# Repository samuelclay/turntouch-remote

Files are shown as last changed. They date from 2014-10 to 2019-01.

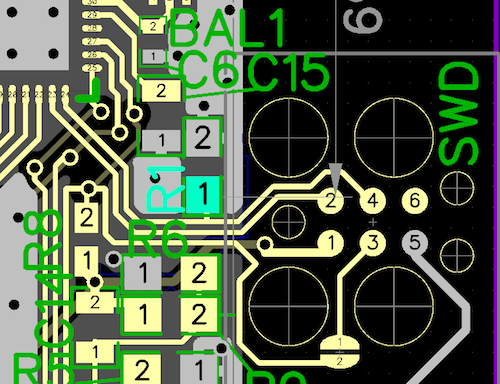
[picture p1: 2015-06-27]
doc/Screen Shot 2013-09-09 at 9.54.04 PM.png

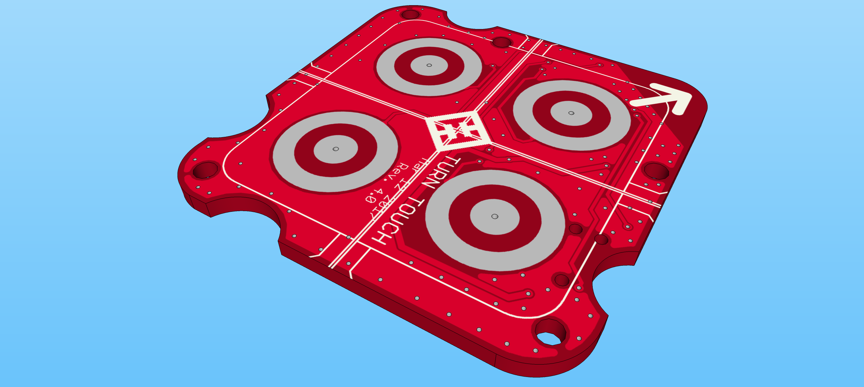
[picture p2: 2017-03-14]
remote eagle/turntuch-bottom-layer.png

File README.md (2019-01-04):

# Turn Touch remote firmware, schematic, and board layout
> The design files used for the nrf51-based Turn Touch remote.

<a href="https://turntouch.com"><br />Available at turntouch.com</a>

[][license-url]



## Screenshots of the board design files

| PCB | EAGLE |
|:---:|:---:|
|  |  |

| Top | Bottom |
|:---:|:---:|
|  |  |

## Background

You can read the complete documentation and background on the [Turn Touch blog series](http://ofbrooklyn.com/2019/01/3/building-turntouch/#firmware).

## Features of the remote

[Turn Touch](https://turntouch.com) is a smart home remote control carved out of beautiful mahogany wood. This is a remote control for Hue lights, Sonos speakers, and all the other connected devices in your home. Turn Touch works on iOS and macOS, giving you control of your music, videos, presentations, and more. 

- [x] **Extraordinary design**: This isn't yet another plastic remote. Turn Touch is carved from solid wood and worked to a show-stopping, textured finish. 
- [x] **Well connected**: Turn Touch connects to most smart devices in your home that speak WiFi. And this is just the first version. Over time, there's no telling what you'll be able to control.
- [x] **Always ready**: Turn Touch is always on, always connected, and always ready to take your breath away. Once you connect your Turn Touch via Bluetooth it stays connected and always available, even without the Turn Touch app actively running. And there's no delay, when you press a button the result is instant.
- [x] **Built to last**: Not only will your Turn Touch stand up to drops and shock — its entire circuit board can be inexpensively replaced with newer, future wireless tech. You won't have to buy a new remote every time Apple comes out with a new phone. And instead of flimsy plastic clasps, a set of 8 strong magnets invisibly hold the remote together. 

## Requirements

- macOS or Windows
- nrf51 Development Kit ([$39 on Digikey](https://www.digikey.com/product-detail/en/nordic-semiconductor-asa/NRF51-DK/1490-1038-ND/5022449))
- EAGLE for schematic and board layout
- ARM toolchain for firmware

## Installation

To install dependencies, start here:

    https://devzone.nordicsemi.com/blogs/22/getting-started-with-nrf51-development-on-mac-os-x/

To use gcc, you will need to download:

 * nRF51 SDK
 * S110 SoftDevice
 * J-Link by Segger
 * srec_cat

    ```$ brew install srecord```

 * GCC ARM Embedded

    When installing GCC tools, do not use "The Unarchiver". It messes up the symlinks for
    all of the binaries. Make sure to use "Archive Utility"
    ```
    $ mv -f ~/Downloads/gcc-arm-none-eabi-4_9-2015q2 ~/projects/code/
    $ ln -s ~/projects/code/gcc-arm-none-eabi-4_9-2015q2 /usr/local/gcc-arm-none-eabi-4_9-2015q2
    ```

 * ./bin/nrfjprog.sh into /usr/local/bin/nrfjprog

### Running

    $ make
    $ make bootloader
    $ make flash
    $ ./bin/nrfjprog.sh --rtt

### Build on Windows

#### Build DFU package

    $ C:\Keil_v5\ARM\ARMCC\bin\fromelf.exe --bin --output Z:\remote\ble_peripheral\ble_app_template\pca10028\s110\arm5\_build\nrf51422_xxac_s110.bin Z:\remote\ble_peripheral\ble_app_template\pca10028\s110\arm5\_build\nrf51422_xxac_s110.axf

    $ & 'C:\Program Files (x86)\Nordic Semiconductor\Master Control Panel\3.10.0.14\nrf\nrfutil.exe' dfu genpkg --sd-req 0xfffe --application Z:\remote\ble_peripheral\ble_app_template\pca10028\s110\arm5\_build\nrf51422_xxac_s110.bin --application-version 0x06 --dev-revision 0x01 Z:\remote\ble_peripheral\nrf51_06.zip

##### Back on Mac

    $ cp ../ble_peripheral/nrf51_*.zip ../../app/Turn\ Touch\ Mac/DFU/firmwares/
    $ cp ../ble_peripheral/nrf51_*.zip ../../ios/Turn\ Touch\ iOS/DFU/

##### In Xcode (in both turntouch-mac/turntouch-ios repos)

In Supporting Files/defaults.plist, change `TT:firmware:version`

#### Build flash hex

    $ mergehex -m Z:/remote/firmware/libs/components/softdevice/s110/hex/s110_nrf51_8.0.0_softdevice.hex Z:/remote/ble_peripheral/dfu/bootloader/pca10028/dual_bank_ble_s110/arm5/_build/nrf51422_xxac.hex Z:/remote/ble_peripheral/ble_app_template/pca10028/s110/arm5/_build/nrf51422_xxac_s110.hex -o Z:/remote/ble_peripheral/nrf51_sd_bootloader_app.hex

#### `make flashwin` on Mac in firmware/

### Upgrading to latest nrf51 SDK

 1) Replace app_error.c with RTT logs
 2) Add BSP_BUTTON_ACTION_LONG_PUSH and BSP_BUTTON_ACTION_RELEASE to bsp.c

## Contribute

We would love you for the contribution to the **Turn Touch remote firmware**. Feel free to submit a Pull Request with the improvements or additions you've made.

## Turn Touch open source repositories and documentation

Everything about Turn Touch is open source and well documented. Here are all of Turn Touch's repos:

* [Turn Touch Mac OS app](https://github.com/samuelclay/turntouch-mac/)
* [Turn Touch iOS app](https://github.com/samuelclay/turntouch-ios/)
* [Turn Touch remote firmware and board layout](https://github.com/samuelclay/turntouch-remote/)
* [Turn Touch enclosure, CAD, and CAM](https://github.com/samuelclay/turntouch-enclosure/)

The entire Turn Touch build process is also documented:
* <a href="http://ofbrooklyn.com/2019/01/3/building-turntouch/">Everything you need to build your own Turn Touch smart remote<br /><img src="https://s3.amazonaws.com/static.newsblur.com/turntouch/blog/1*1_w7IlHISYWdQjIGPcxRkQ.jpeg" width="400"></a>
* <a href="http://ofbrooklyn.com/2019/01/3/building-turntouch/#firmware">Step one: Laying out the buttons and writing the firmware <br /><img src="https://s3.amazonaws.com/static.newsblur.com/turntouch/blog/1*K_ERgjIZiFIX5yDOa5JJ7g.png" width="400"></a>
* <a href="http://ofbrooklyn.com/2019/01/3/building-turntouch/#cad">Step two: Designing the remote to have perfect button clicks <br /><img src="https://s3.amazonaws.com/static.newsblur.com/turntouch/blog/1*iXMqpq5IsfudAeT3GZlLFA.png" width="400"></a>
* <a href="http://ofbrooklyn.com/2019/01/3/building-turntouch/#cnc">Step three: CNC machining and fixturing to accurately cut wood <br /><img src="https://s3.amazonaws.com/static.newsblur.com/turntouch/blog/1*SYmywFE5tY3GBO9t9lcTiA.png" width="400"></a>
* <a href="http://ofbrooklyn.com/2019/01/3/building-turntouch/#laser">Step four: Inlaying the mother of pearl <br /><img src="https://s3.amazonaws.com/static.newsblur.com/turntouch/blog/1*kl8WDuTd0RpCkkipLeHx0g.png" width="400"></a>

## Author

Samuel Clay – [@samuelclay](https://twitter.com/samuelclay) – [samuelclay.com](http://samuelclay.com)

Distributed under the MIT license. See ``LICENSE`` for more information.

[https://github.com/samuelclay/turntouch-mac](https://github.com/samuelclay)

[swift-image]:https://img.shields.io/badge/swift-3.0-orange.svg
[swift-url]: https://swift.org/
[license-image]: https://img.shields.io/badge/License-MIT-blue.svg
[license-url]: LICENSE
[travis-image]: https://img.shields.io/travis/dbader/node-datadog-metrics/master.svg?style=flat-square
[travis-url]: https://travis-ci.org/dbader/node-datadog-metrics
[codebeat-image]: https://codebeat.co/badges/c19b47ea-2f9d-45df-8458-b2d952fe9dad
[codebeat-url]: https://codebeat.co/projects/github-com-vsouza-awesomeios-com

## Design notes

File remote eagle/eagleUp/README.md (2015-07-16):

Steps to import Eagle model into Inventor:

1) Run UDP for EagleUp, use 0 mm for height
2) Import into Sketchup using EagleUp plugin
3) In Sketchup, hit ⌘1 to show top view
4) Export as .DXF (autocad drawing) in 2d
5) Import in Inventor as DXF
6) Create a new part file with PCB, extrude sketch to height 0.7mm = 0.028"

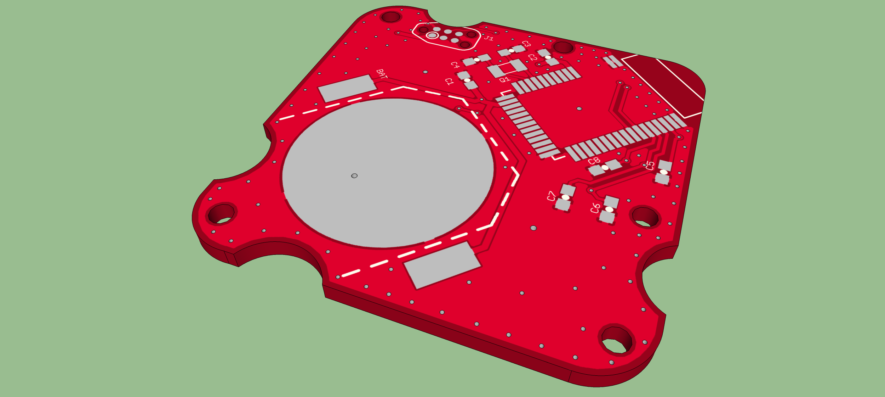
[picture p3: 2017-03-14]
remote eagle/turntuch-top-layer.png

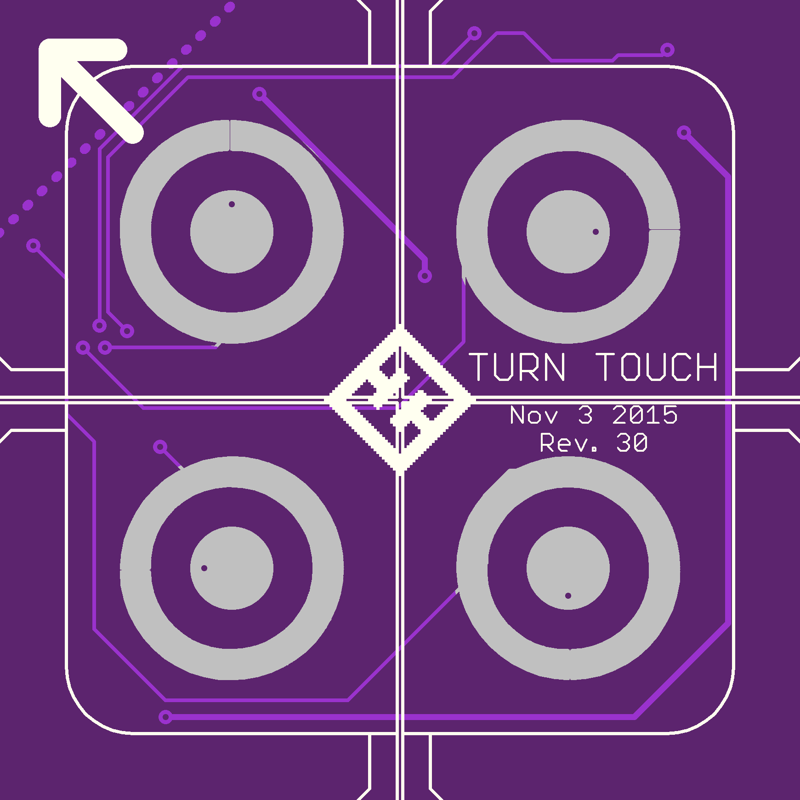
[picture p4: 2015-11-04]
remote eagle/eagleUp/eagleUp_remote_board_bottom.png

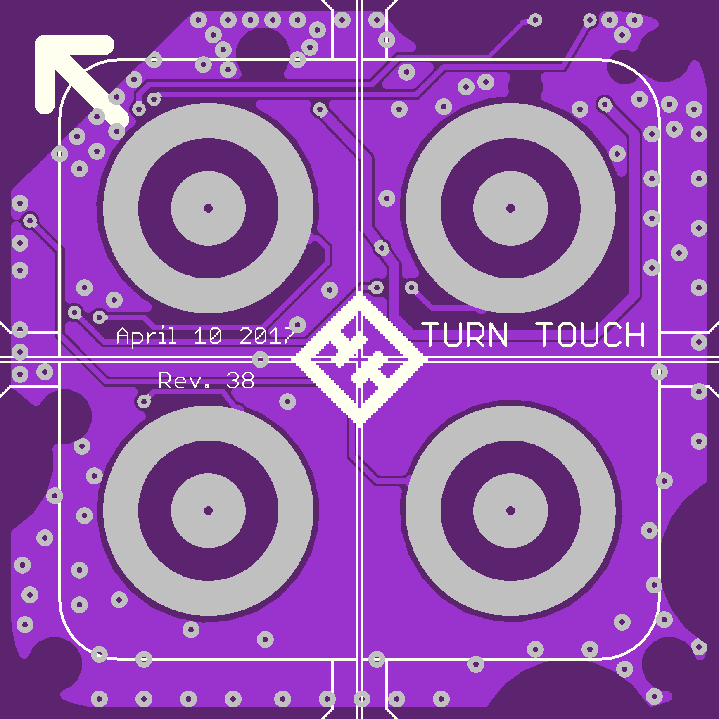
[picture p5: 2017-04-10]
remote eagle/eagleUp/rev 38 eagleUp_turntouch-remote-master_board_bottom.png

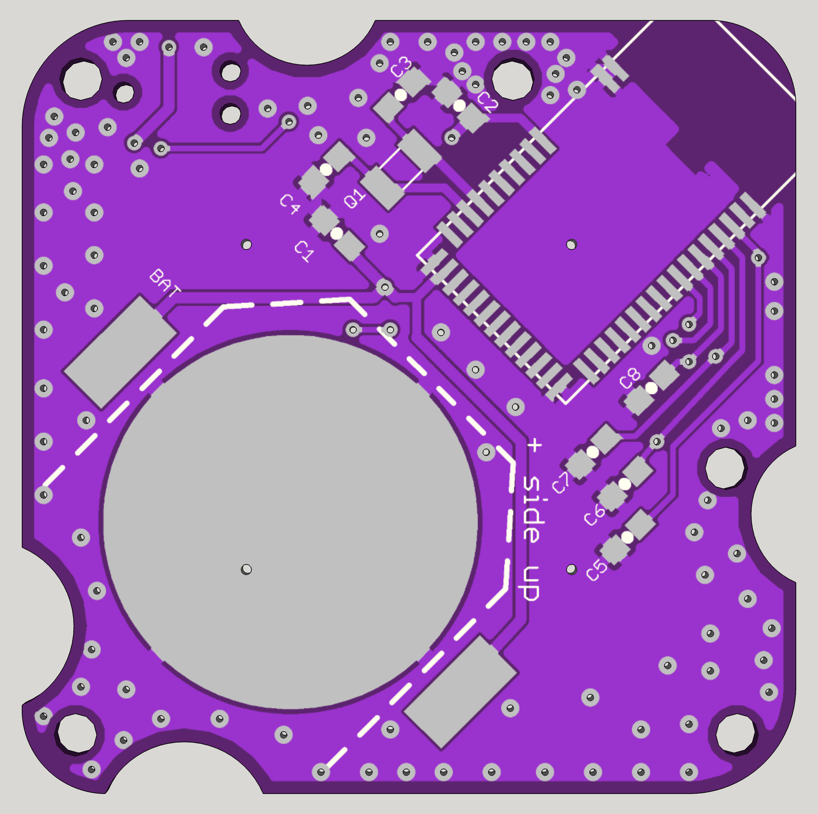
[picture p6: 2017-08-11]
remote eagle/eagleUp/rev40 eagleUp_turntouch-remote-master_board_top.png

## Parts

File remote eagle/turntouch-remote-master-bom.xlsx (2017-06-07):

 | TURNTUCH REMOTE MASTER
 | Bill Of Materials – rev 35
Item | Ref. Design | Quantity | Value | Manufacturer | Manufacturer ID | Distributor | Distributor ID | Description | Package | Type | Price | Price (multiple)
1 | U1 | 1 |  | Raytac | MDBT40-256RV3 | www.raytac.com |  | nRF51422 BLE SoC module with PCB trace antenna |  | SMD module | 5.00 | 3.55
2 | X1 | 1 | 32.768 kHz | EPSON | FC-135R 32.7680KA-AC3 | www.digikey.com | SER4072CT-ND | 32.768kHz ±20ppm Crystal 9pF 50 kOhm -40°C ~ 85°C Surface Mount 2-SMD, No Lead (DFN, LCC) | Cut Tape | 2 SMD 3.2x1.5 | 0.80 | 0.58
3 | C1 | 1 | 1uF | Samsung Electro-Mechanics America, Inc. | CL10B105KP8NNNC | www.digikey.com | 1276-1946-1-ND | 1µF ±10% 10V Ceramic Capacitor X7R 0603 (1608 Metric) | Cut Tape | C0603 | 0.10 | 0.01
4 | C2 | 1 | 1uF | Samsung Electro-Mechanics America, Inc. | CL10B105KP8NNNC | www.digikey.com | 1276-1946-1-ND | 1µF ±10% 10V Ceramic Capacitor X7R 0603 (1608 Metric) | Cut Tape | C0603 | 0.10 | 0.01
5 | C3 | 1 | 12pF | Samsung Electro-Mechanics America, Inc. | CL10C120FB8NNNC | www.digikey.com | 1276-2175-1-ND | 12pF 50V Ceramic Capacitor C0G, NP0 0603 (1608 Metric) 0.063" L x 0.031" W (1.60mm x 0.80mm) | Cut Tape | C0603 | 0.10 | 0.02
6 | C4 | 1 | 12pF | Samsung Electro-Mechanics America, Inc. | CL10C120FB8NNNC | www.digikey.com | 1276-2175-1-ND | 12pF 50V Ceramic Capacitor C0G, NP0 0603 (1608 Metric) 0.063" L x 0.031" W (1.60mm x 0.80mm) | Cut Tape | C0603 | 0.10 | 0.02
7 | C5 | 1 | 100nF | Kemet | C0603C104K8RACTU | www.digikey.com | 399-1095-1-ND | 0.1µF ±10% 10V Ceramic Capacitor X7R 0603 (1608 Metric) | Cut Tape | C0603 | 0.10 | 0.01
8 | C6 | 1 | 100nF | Kemet | C0603C104K8RACTU | www.digikey.com | 399-1095-1-ND | 0.1µF ±10% 10V Ceramic Capacitor X7R 0603 (1608 Metric) | Cut Tape | C0603 | 0.10 | 0.01
9 | C7 | 1 | 100nF | Kemet | C0603C104K8RACTU | www.digikey.com | 399-1095-1-ND | 0.1µF ±10% 10V Ceramic Capacitor X7R 0603 (1608 Metric) | Cut Tape | C0603 | 0.10 | 0.01
10 | C8 | 1 | 100nF | Kemet | C0603C104K8RACTU | www.digikey.com | 399-1095-1-ND | 0.1µF ±10% 10V Ceramic Capacitor X7R 0603 (1608 Metric) | Cut Tape | C0603 | 0.10 | 0.01
11 | BAT1 | 1 |  | Linx Technologies Inc. | BAT-HLD-001 | www.digikey.com | BAT-HLD-001-ND | HOLDER BATTERY 20MM COIN | Cut Tape | SMD module | 0.28 | 0.22
12 | TS1; TS2; TS3; TS4 | 1 |  | CMD |  | www.china-metaldome.com |  | Metal dome sticker array backed with adhesive tape | Bulk | Sticker array | $2.00 | $0.25
 |  |  |  |  |  |  |  |  |  | TOTAL SUM | $8.88 | $4.68

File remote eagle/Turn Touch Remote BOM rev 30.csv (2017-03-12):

Part/Designator | Manufacturer Part # | Qty | Value | Device | Package | Digikey
C3, C4 | CL10C140JB8NNNC | 2 | 14pF | CAP CER 14PF 50V NP0 0603 | 0603-CAP | 1276-2187-1-ND
C1, C2 | CL10B105KP8NNNC | 2 | 1uF | CAP CER 1UF 10V X7R 0603 | 0603-CAP | 1276-1946-1-ND
U$6 | BU2032SM-BT-GTR | 1 | COINCELLHOLDER | BU2032SM-BT-GTR | 20MMCOINCELL | BU2032SM-BT-GCT-ND
Q1 | ABS07-32.768KHZ-9-T | 1 | 32.7680KHZ 9PF | CRYSTAL.ABS07 | ABS07 | 535-9544-1-ND
U$5 | MDBT40-256RV3 | 1 | MDBT40-256RV3 | Raytac nRF51822 based module with chip antenna | MDBT40

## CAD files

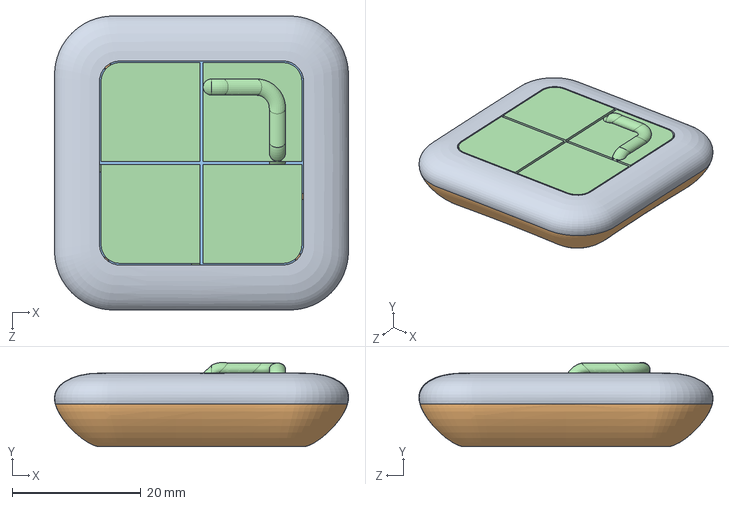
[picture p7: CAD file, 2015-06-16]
enclosure/solidworks/Remote Assembly.SLDASM
45.7 x 13.1 x 45.7 mm
Remote Top
Remote Buttons

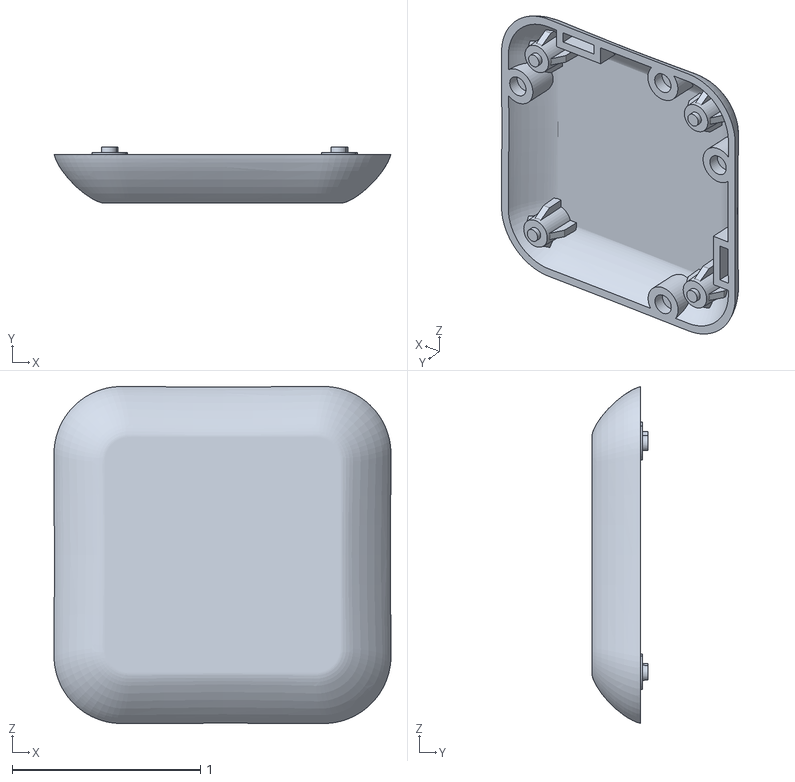
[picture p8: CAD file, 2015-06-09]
enclosure/solidworks/STLs/Remote Assembly - Remote Bottom-1.STL
1.79 x 0.3 x 1.79

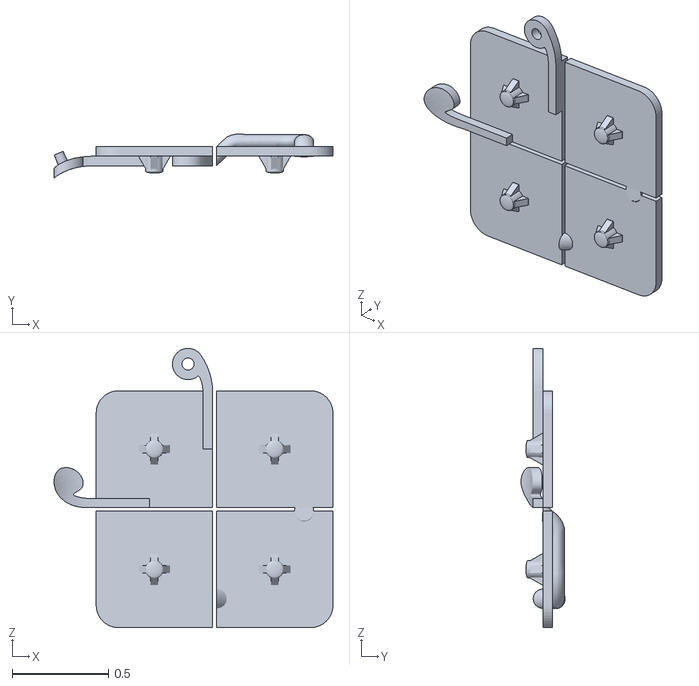
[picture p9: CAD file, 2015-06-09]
enclosure/solidworks/STLs/Remote Assembly - Remote Buttons-1.STL
1.45 x 0.229 x 1.45

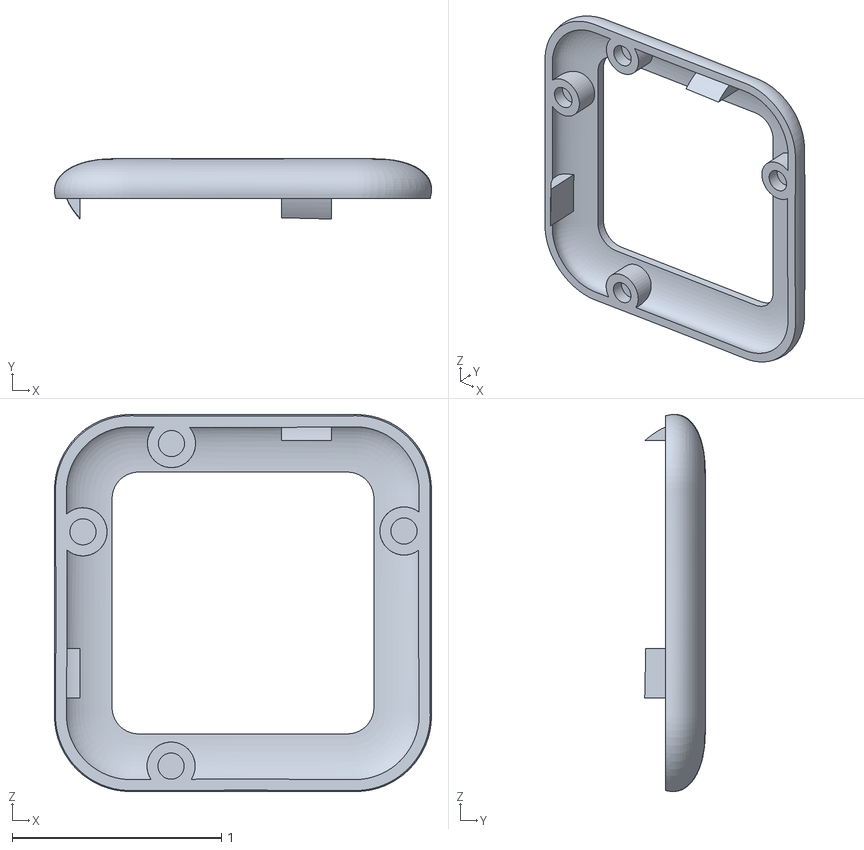
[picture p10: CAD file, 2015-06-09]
enclosure/solidworks/STLs/Remote Assembly - Remote Top-1.STL
1.80 x 0.29 x 1.80

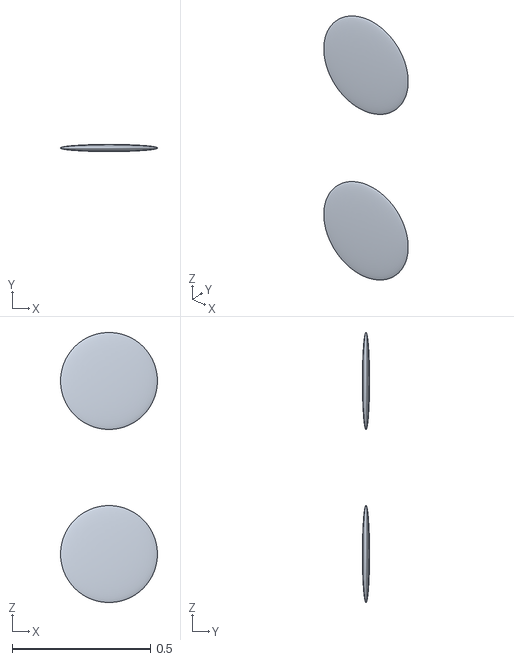
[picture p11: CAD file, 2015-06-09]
enclosure/solidworks/STLs/Remote Assembly - PCB-3.STL
0.35 x 0.026 x 0.975

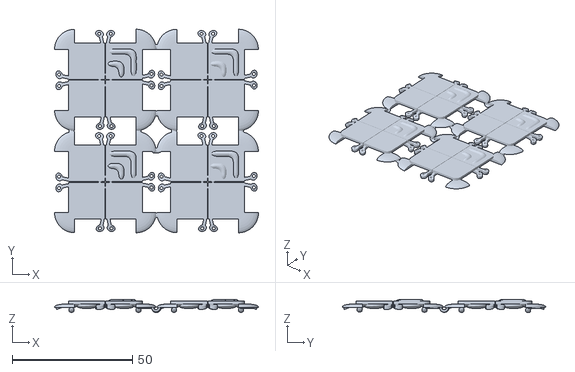
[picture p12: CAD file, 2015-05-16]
enclosure/buttons.stl
84.7 x 84.5 x 5.56

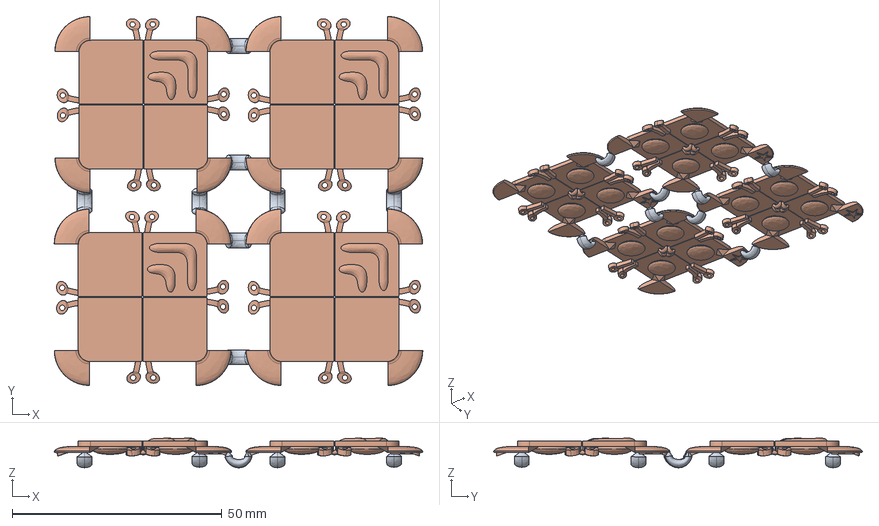
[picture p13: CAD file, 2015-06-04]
enclosure/rhino/bottoms.stp
87.9 x 88.0 x 7.06 mm

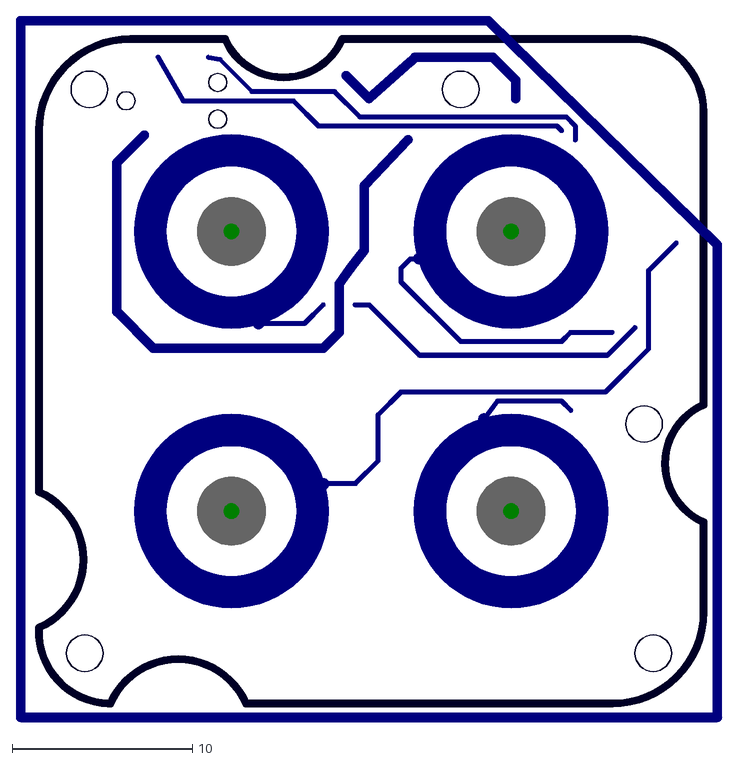
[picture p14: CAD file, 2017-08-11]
remote eagle/turntouch-remote-master.dxf
39.1 x 39.1

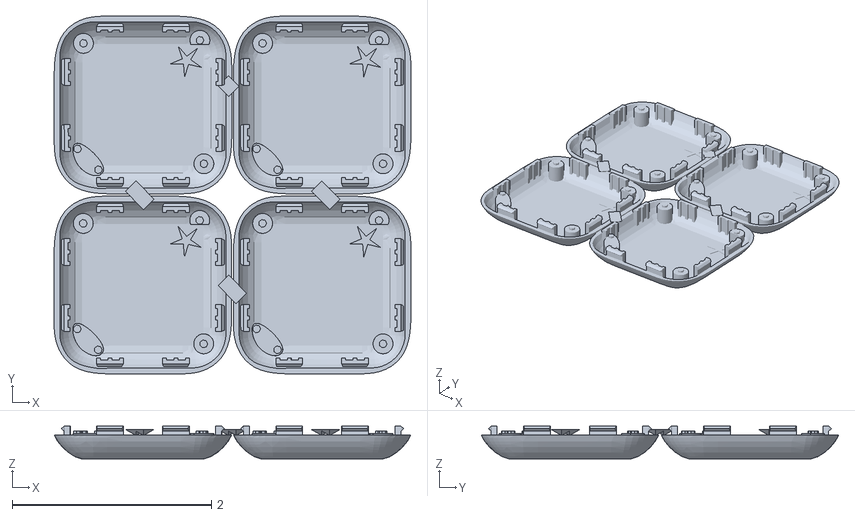
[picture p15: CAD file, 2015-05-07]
enclosure/bottoms.stl
3.59 x 3.60 x 0.331

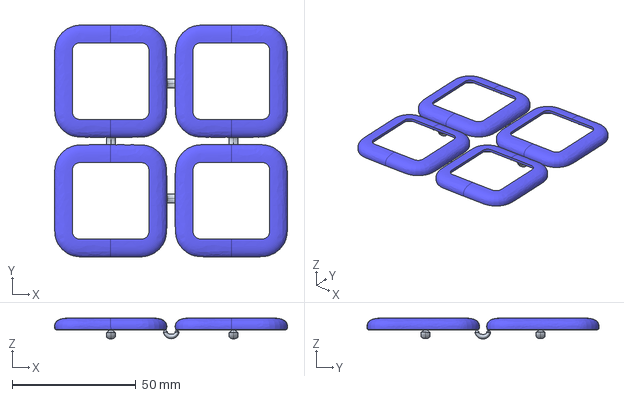
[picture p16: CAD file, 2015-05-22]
enclosure/rhino/tops.stp
94.2 x 93.9 x 8.49 mm

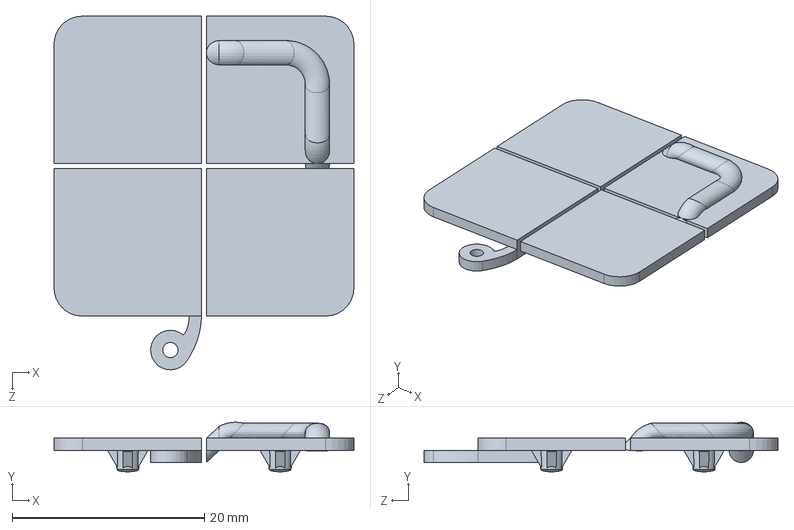
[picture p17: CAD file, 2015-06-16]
enclosure/solidworks/Remote Buttons.SLDPRT
31.2 x 5.17 x 36.8 mm

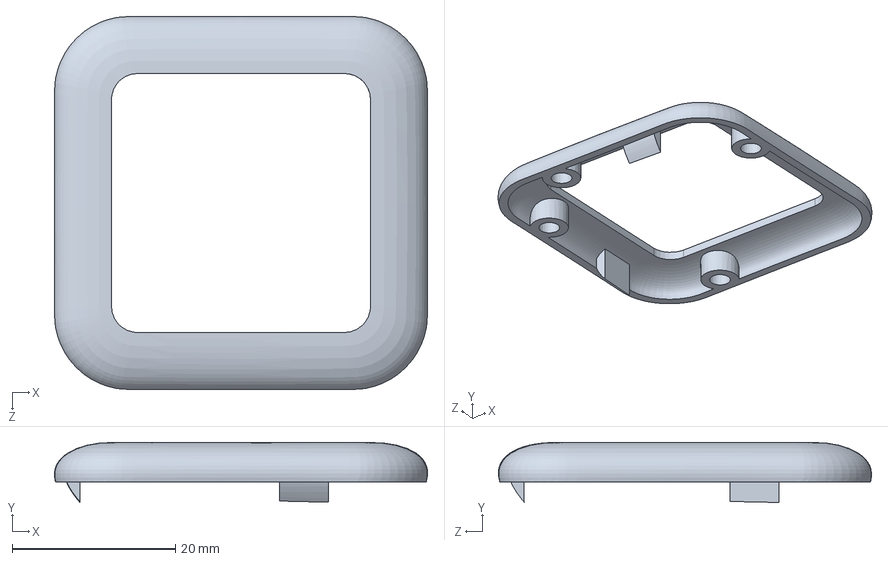
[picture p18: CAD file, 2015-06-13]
enclosure/solidworks/Remote Top.sldprt
45.7 x 7.36 x 45.7 mm

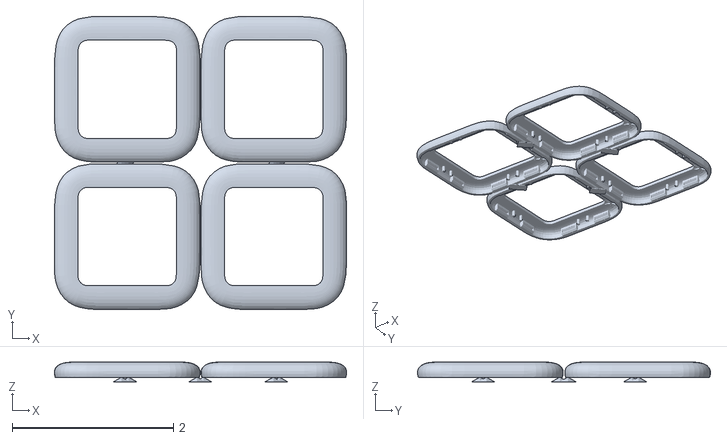
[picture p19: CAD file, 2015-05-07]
enclosure/tops.stl
3.63 x 3.64 x 0.246

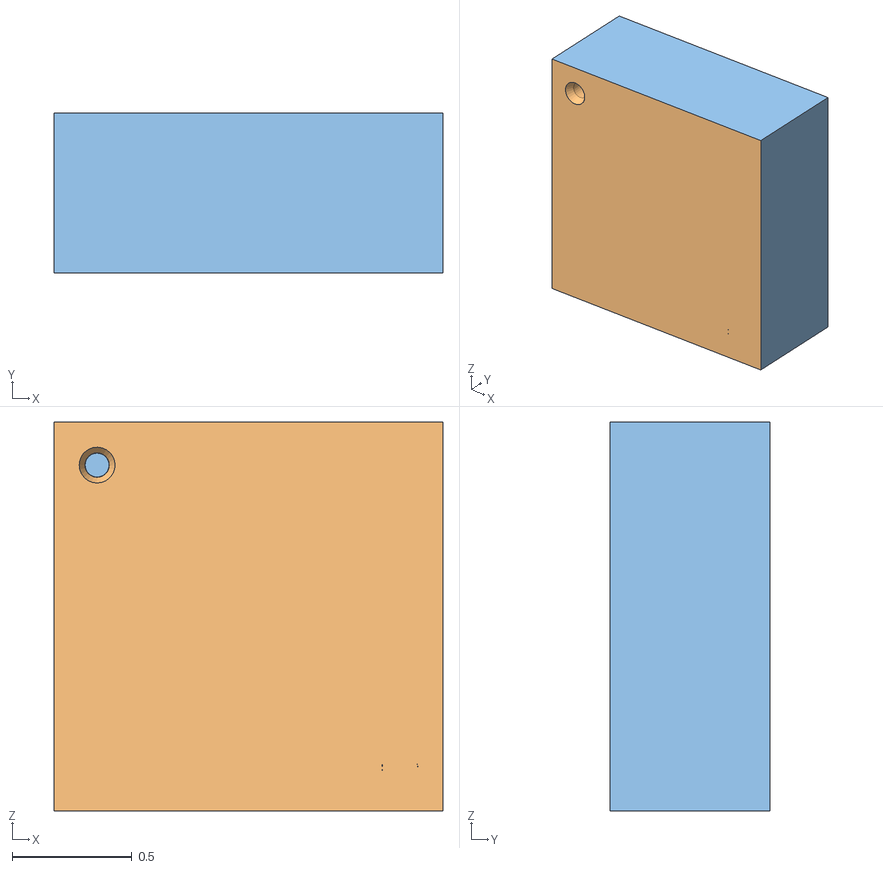
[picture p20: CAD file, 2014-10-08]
enclosure/Remote enclosure.obj
1.63 x 0.67 x 1.62
Mesh1 PCB Model
Mesh91 Bottom___05__walls_ Model
Mesh102 Top___05__walls_ Model
Mesh116 Button_cap1 Model
Mesh120 Button_cap2 Model
Mesh124 Button_cap3 Model
Mesh128 Button_cap4 Model

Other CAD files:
enclosure/rhino/buttons.stp
enclosure/rhino/remote.stp
enclosure/solidworks/PCB.SLDPRT
enclosure/rhino/button.stp
enclosure/Remote Enclosure v2.3dm
enclosure/Remote Enclosure.skp
enclosure/Remote r14.3dm
enclosure/rhino/bottom.stl
enclosure/rhino/bottom.stp
enclosure/rhino/button.stl
enclosure/rhino/top.stl
enclosure/rhino/top.stp
enclosure/solidworks/Remote Bottom.sldprt
enclosure/solidworks/Remote Shell.SLDPRT
enclosure/solidworks/STLs/PCB.STL

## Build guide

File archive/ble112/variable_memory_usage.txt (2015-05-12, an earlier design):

132
0:0	GAP_AD_FLAG_BREDR_NOT_SUPPORTED
0:0	GAP_AD_FLAG_GENERAL_DISCOVERABLE
0:0	GAP_AD_FLAG_LIMITED_DISCOVERABLE
0:0	GAP_AD_FLAG_MASK
0:0	GAP_AD_FLAG_SIMULTANEOUS_LEBREDR_CTRL
0:0	GAP_AD_FLAG_SIMULTANEOUS_LEBREDR_HOST
0:0	GAP_SCAN_HEADER_ADV_DIRECT_IND
0:0	GAP_SCAN_HEADER_ADV_DISCOVER_IND
0:0	GAP_SCAN_HEADER_ADV_IND
0:0	GAP_SCAN_HEADER_ADV_NONCONN_IND
0:0	GAP_SCAN_HEADER_CONNECT_REQ
0:0	GAP_SCAN_HEADER_SCAN_REQ
0:0	GAP_SCAN_HEADER_SCAN_RSP
0:0	attclient_attribute_value_type_indicate
0:0	attclient_attribute_value_type_indicate_rsp_req
0:0	attclient_attribute_value_type_notify
0:0	attclient_attribute_value_type_read
0:0	attclient_attribute_value_type_read_blob
0:0	attclient_attribute_value_type_read_by_type
0:0	attributes_attribute_change_reason_write_command
0:0	attributes_attribute_change_reason_write_request
0:0	attributes_attribute_change_reason_write_request_user
0:0	attributes_attribute_status_flag_indicate
0:0	attributes_attribute_status_flag_notify
0:0	c_appearance
0:0	c_battery_level
0:0	c_conn_latency
0:0	c_conn_timeout
0:0	c_device_name
0:0	c_gpio_status
0:0	c_interval_max
0:0	c_interval_min
0:0	c_manufacturer_name
0:0	c_mode_duration
0:0	c_model_number
0:0	c_nickname
0:0	c_serial_number
0:0	connection_completed
0:0	connection_connected
0:0	connection_encrypted
0:0	connection_parameters_change
0:0	gap_ad_type_flags
0:0	gap_ad_type_localname_complete
0:0	gap_ad_type_localname_short
0:0	gap_ad_type_none
0:0	gap_ad_type_services_128bit_all
0:0	gap_ad_type_services_128bit_more
0:0	gap_ad_type_services_16bit_all
0:0	gap_ad_type_services_16bit_more
0:0	gap_ad_type_services_32bit_all
0:0	gap_ad_type_services_32bit_more
0:0	gap_ad_type_txpower
0:0	gap_address_type_public
0:0	gap_address_type_random
0:0	gap_adv_policy_all
0:0	gap_adv_policy_whitelist_all
0:0	gap_adv_policy_whitelist_connect
0:0	gap_adv_policy_whitelist_scan
0:0	gap_broadcast
0:0	gap_directed_connectable
0:0	gap_discover_generic
0:0	gap_discover_limited
0:0	gap_discover_observation
0:0	gap_general_discoverable
0:0	gap_limited_discoverable
0:0	gap_non_connectable
0:0	gap_non_discoverable
0:0	gap_scan_policy_all
0:0	gap_scan_policy_whitelist
0:0	gap_scannable_non_connectable
0:0	gap_undirected_connectable
0:0	gap_user_data
0:0	sm_bonding_key_addr_public
0:0	sm_bonding_key_addr_static
0:0	sm_bonding_key_csrk
0:0	sm_bonding_key_edivrand
0:0	sm_bonding_key_irk
0:0	sm_bonding_key_ltk
0:0	sm_bonding_key_masterid
0:0	sm_io_capability_displayonly
0:0	sm_io_capability_displayyesno
0:0	sm_io_capability_keyboarddisplay
0:0	sm_io_capability_keyboardonly
0:0	sm_io_capability_noinputnooutput
0:0	system_endpoint_api
0:0	system_endpoint_script
0:0	system_endpoint_test
0:0	system_endpoint_uart0
0:0	system_endpoint_uart1
0:0	system_endpoint_usb
0:0	PORT0_PIN_SELECT_MASK
0:0	PORT1_PIN_SELECT_MASK
0:0	DEFAULT_INTERVAL_MIN
0:0	DEFAULT_INTERVAL_MAX
0:0	DEFAULT_CONN_LATENCY
0:0	DEFAULT_CONN_TIMEOUT
0:0	DEFAULT_MODE_DURATION
0:0	ps_interval_min_uuid
0:0	ps_interval_max_uuid
0:0	ps_conn_latency_uuid
0:0	ps_conn_timeout_uuid
0:0	ps_mode_duration_uuid
0:0	ps_nickname_uuid
0:4	connected
4:4	advertising
8:4	io_status
12:4	ipr_result
16:4	ipr_port
20:4	ipr_data
24:4	port0_delta
28:4	port1_delta
32:4	irq_pos
36:4	holding_irq
40:2	last_sent_state
42:4	bat_pct
46:4	last_bat_pct
50:4	ps_interval_min
54:4	ps_interval_max
58:4	ps_conn_latency
62:4	ps_conn_timeout
66:4	ps_mode_duration
70:12	t
82:4	ps_error
86:4	ps_len
90:10	ps_data
100:32	ps_nickname

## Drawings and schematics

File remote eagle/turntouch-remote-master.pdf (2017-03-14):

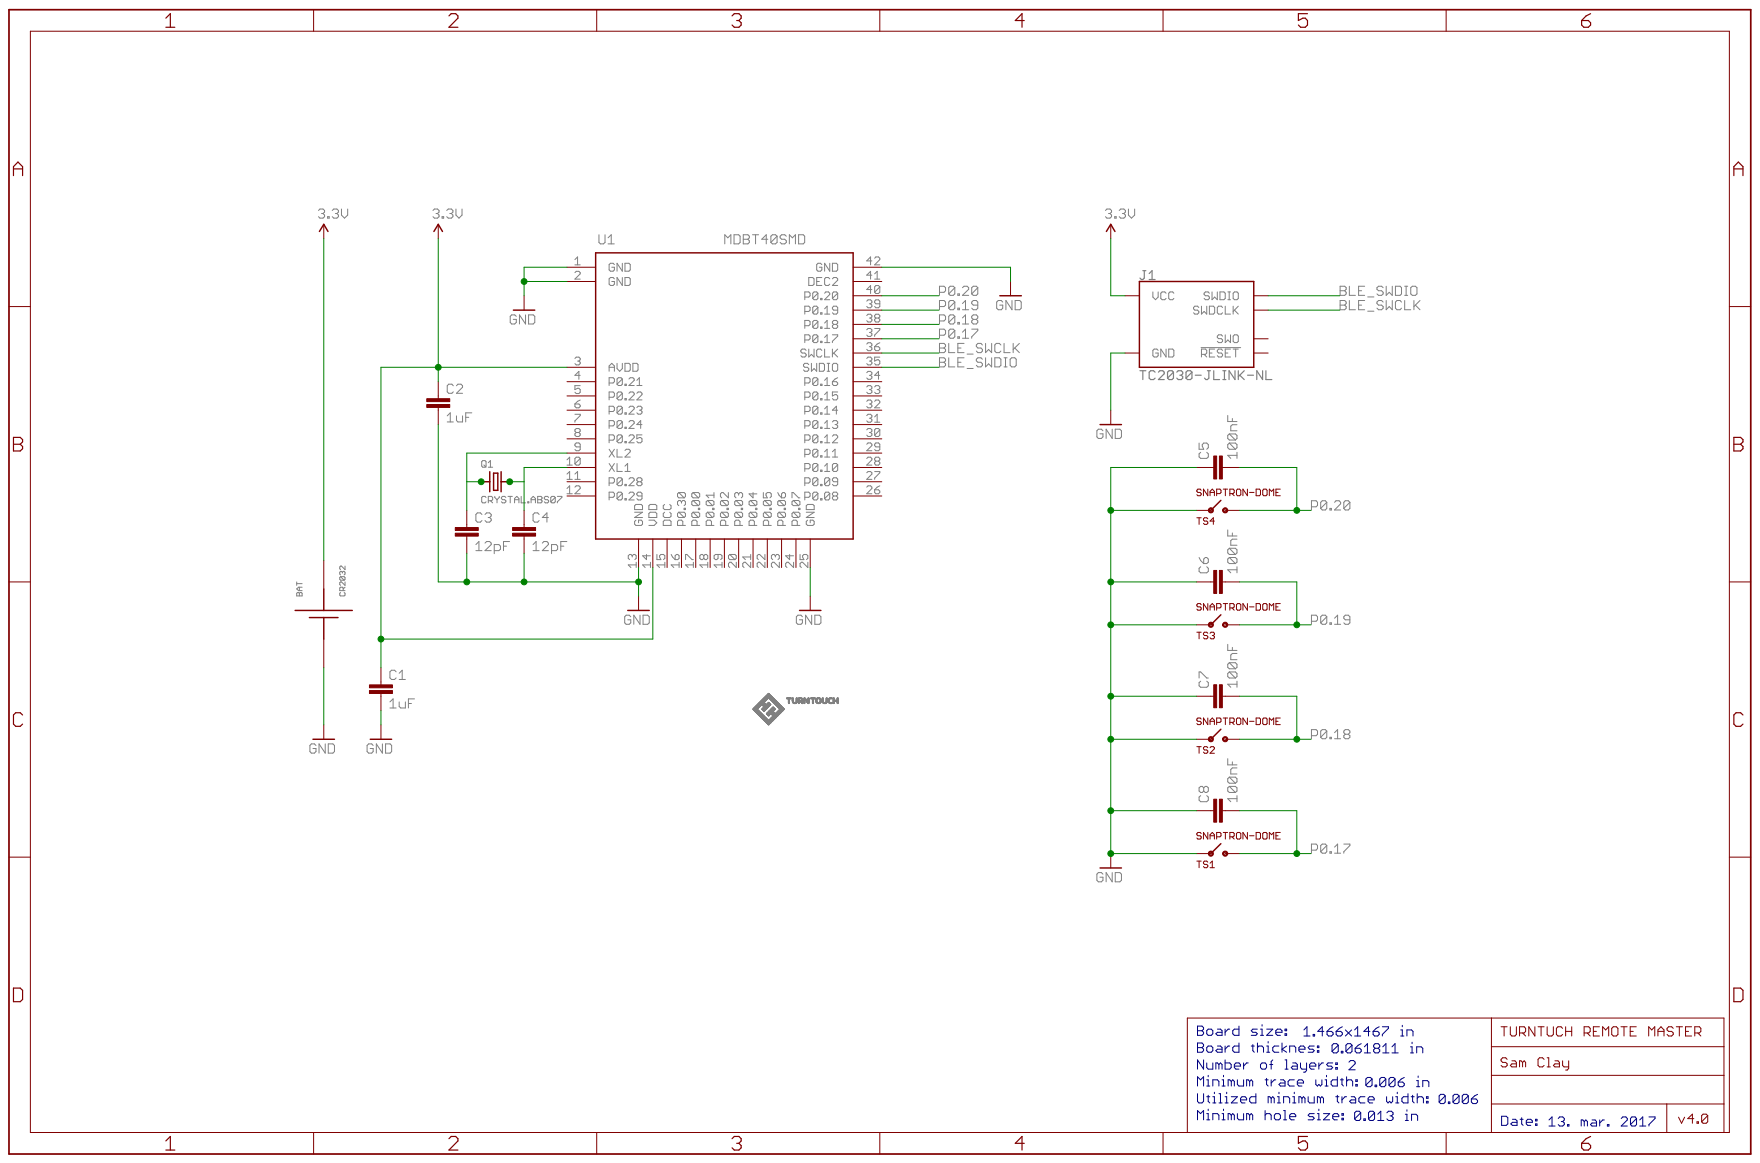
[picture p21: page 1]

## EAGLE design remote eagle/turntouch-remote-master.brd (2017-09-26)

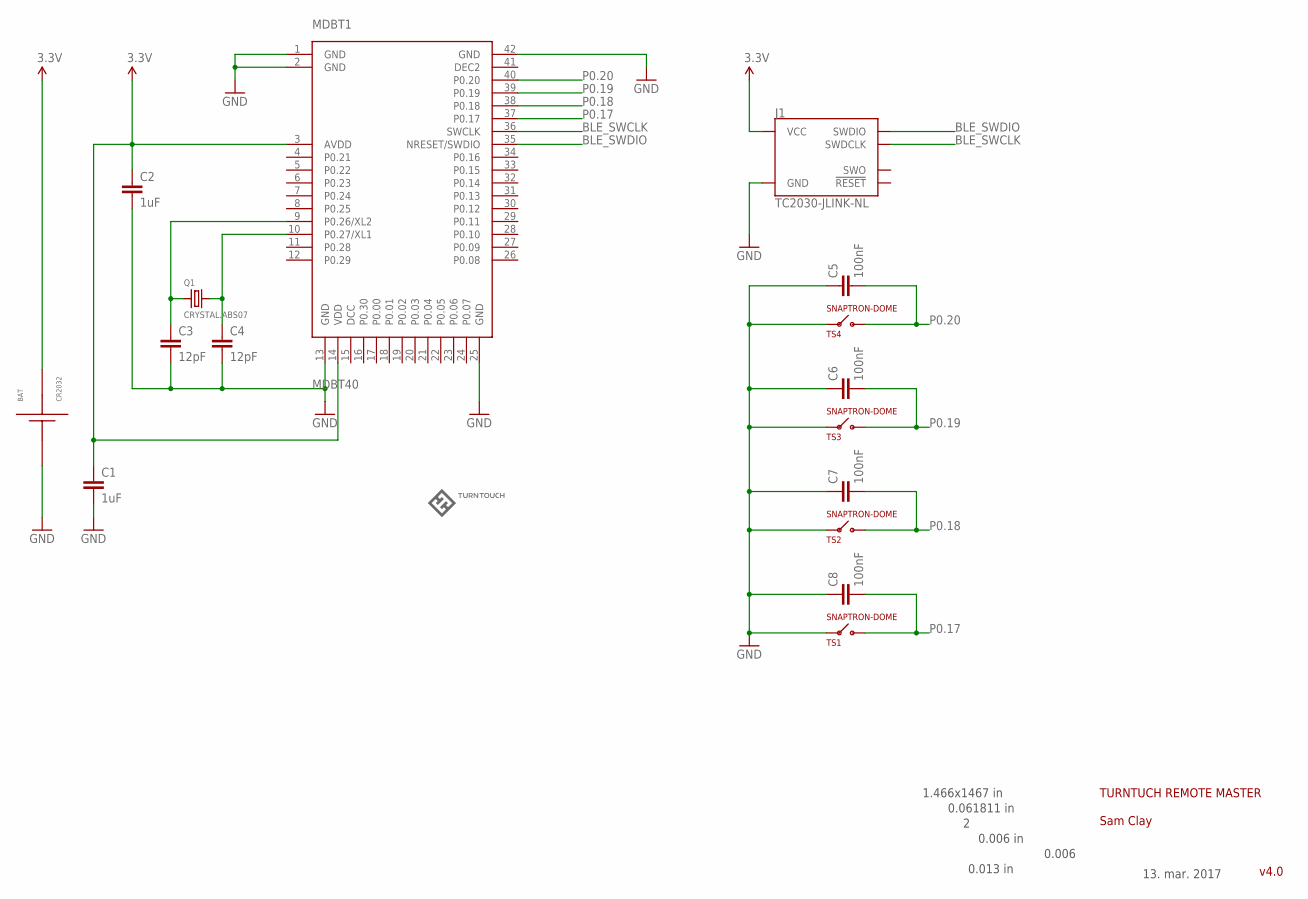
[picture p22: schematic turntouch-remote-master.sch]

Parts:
BAT: CR2032
C1, C2: 1uF; 0603-CAP
C3, C4: 12pF; 0603-CAP
C5, C6, C7, C8: 100nF; 0603-CAP
J1: TC2030-JLINK-NL; TC2030-IDC-NL
LOGO: TURNTOUCHLOGO200DPI; LOGO
MDBT1: MDBT40
Q1: CRYSTAL.ABS07; ABS07
TS1, TS2, TS3, TS4: SNAPTRON-DOME; DOME-M-SERIES

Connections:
3.3V: BAT.P$1 (VBAT), BAT.P$2 (VBAT), C1.1, C2.1, J1.1 (VCC), MDBT1.3 (AVDD), MDBT1.14 (VDD)
BLE_SWCLK: J1.4 (SWDCLK), MDBT1.36 (SWCLK)
BLE_SWDIO: J1.2 (SWDIO), MDBT1.35 (NRESET/SWDIO)
C5: C4.1, MDBT1.10 (P0.27/XL1), Q1.2
GND: BAT.GND, C1.2, C2.2, C3.2, C4.2, C5.1, C6.1, C7.1, C8.1, J1.5 (GND), MDBT1.1 (GND), MDBT1.2 (GND), MDBT1.13 (GND), MDBT1.25 (GND), MDBT1.42 (GND), TS1.P$1 (V), TS1.P$2 (V), TS2.P$1 (V), TS2.P$2 (V), TS3.P$1 (V), TS3.P$2 (V), TS4.P$1 (V), TS4.P$2 (V)
unnamed: C3.1, MDBT1.9 (P0.26/XL2), Q1.1
P0.17: C8.2, MDBT1.37 (P0.17), TS1.P$3 (B)
P0.18: C7.2, MDBT1.38 (P0.18), TS2.P$3 (B)
P0.19: C6.2, MDBT1.39 (P0.19), TS3.P$3 (B)
P0.20: C5.2, MDBT1.40 (P0.20), TS4.P$3 (B)

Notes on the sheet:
1.466x1467 in
0.061811 in
0.006 in
0.006
0.013 in
TURNTUCH REMOTE MASTER
v4.0
13. mar. 2017
Sam Clay

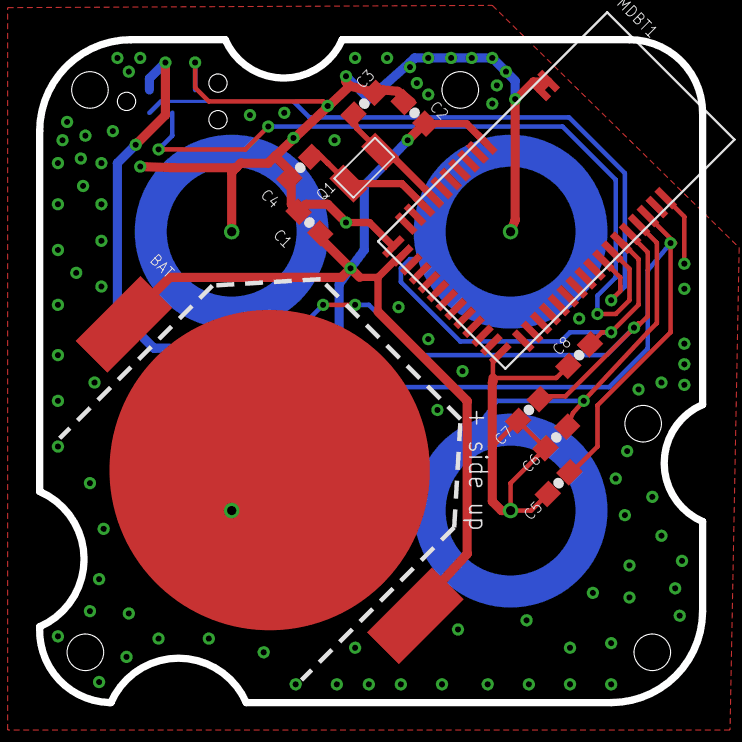
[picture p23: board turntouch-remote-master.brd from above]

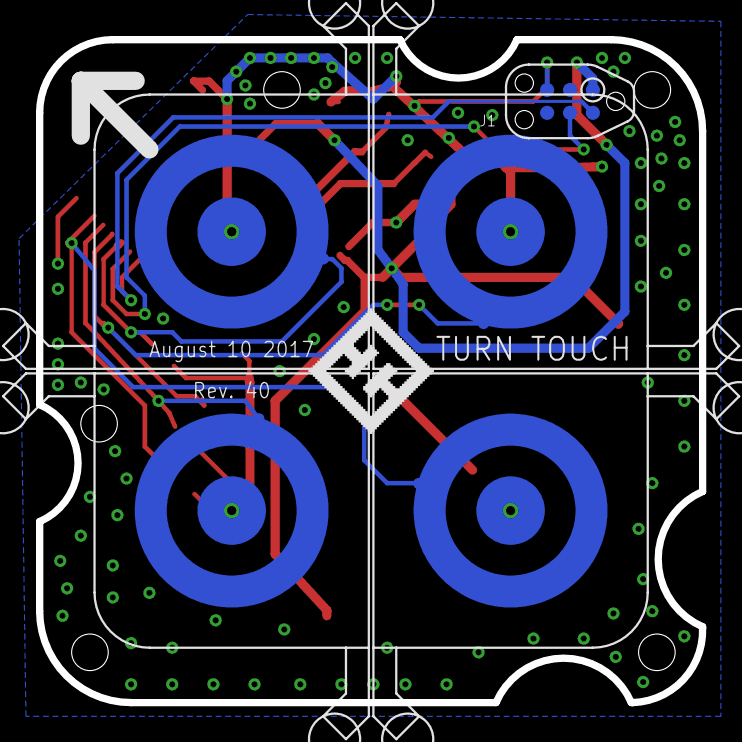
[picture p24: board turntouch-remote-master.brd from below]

Board: 2 copper layers, 36.8 x 36.8 mm, 17 parts (6 on the bottom side), 10 nets.

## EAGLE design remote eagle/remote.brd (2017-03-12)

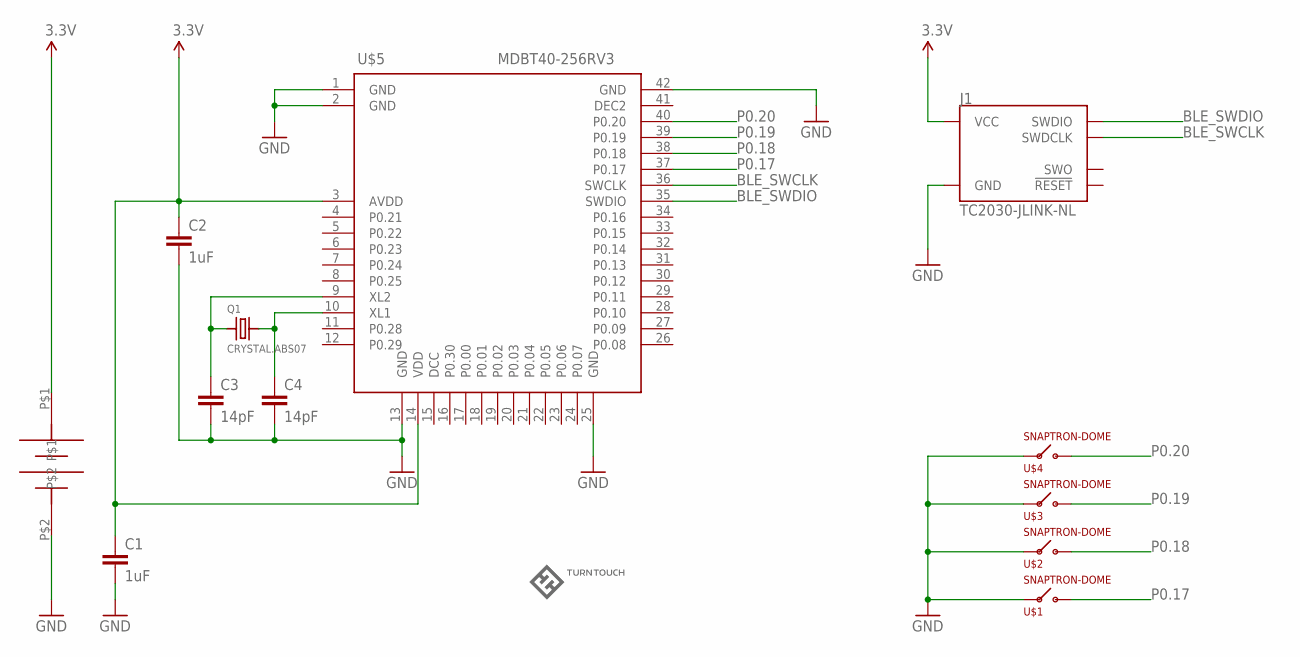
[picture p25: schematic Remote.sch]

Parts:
C1, C2: 1uF; 0603-CAP
C3, C4: 14pF; 0603-CAP
J1: TC2030-JLINK-NL; TC2030-IDC-NL
LOGO: TURNTOUCHLOGO200DPI; LOGO
Q1: CRYSTAL.ABS07; ABS07
U$1, U$2, U$3, U$4: SNAPTRON-DOME; DOME-M-SERIES
U$5: MDBT40-256RV3; MDBT40
U$6: COINCELLHOLDER; 20MMCOINCELL

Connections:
3.3V: C1.1, C2.1, J1.1 (VCC), U$5.3 (AVDD), U$5.14 (VDD), U$6.P$1
BLE_SWCLK: J1.4 (SWDCLK), U$5.36 (SWCLK)
BLE_SWDIO: J1.2 (SWDIO), U$5.35 (SWDIO)
C5: C4.1, Q1.2, U$5.10 (XL1)
GND: C1.2, C2.2, C3.2, C4.2, J1.5 (GND), U$1.P$1 (V), U$1.P$2 (V), U$2.P$1 (V), U$2.P$2 (V), U$3.P$1 (V), U$3.P$2 (V), U$4.P$1 (V), U$4.P$2 (V), U$5.1 (GND), U$5.2 (GND), U$5.13 (GND), U$5.25 (GND), U$5.42 (GND), U$6.P$2
unnamed: C3.1, Q1.1, U$5.9 (XL2)
P0.17: U$1.P$3 (B), U$5.37 (P0.17)
P0.18: U$2.P$3 (B), U$5.38 (P0.18)
P0.19: U$3.P$3 (B), U$5.39 (P0.19)
P0.20: U$4.P$3 (B), U$5.40 (P0.20)

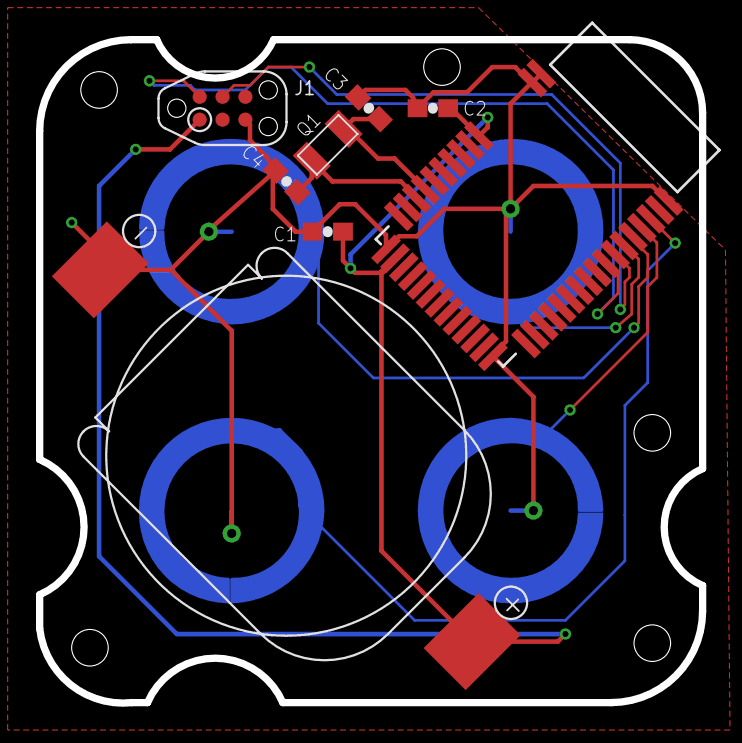
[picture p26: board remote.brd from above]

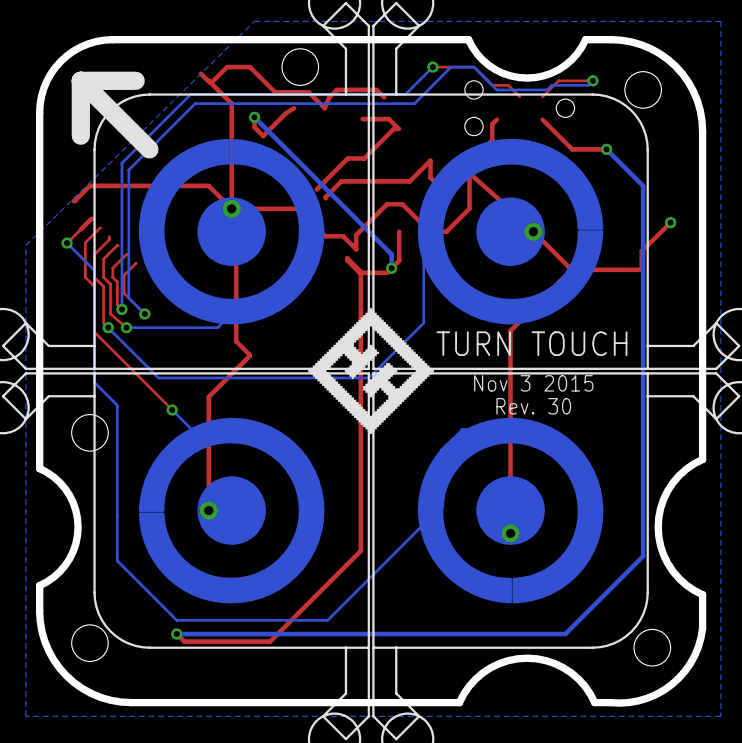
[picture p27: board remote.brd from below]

Board: 2 copper layers, 36.8 x 36.9 mm, 13 parts (5 on the bottom side), 10 nets.

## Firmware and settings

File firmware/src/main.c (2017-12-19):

/* Copyright 2015 Turn Touch. All rights reserved.
 * 
 * This is the main sequence for the Turn Touch Remote.
 * 
 * Includes:
 *   - 4 button GPIOs
 *   - Pin interrupts on buttons
 *   - Timer to watch for long presses to signal mode changes
 *   - Bluetooth Softdevice stack
 * 
 */

#include <stdbool.h>
#include <stdint.h>
#include <inttypes.h>
#include "app_error.h"
#include "app_scheduler.h"
#include "app_timer.h"
#include "app_timer_appsh.h"
#include "app_trace.h"
#include "ble.h"
#include "ble_advdata.h"
#include "ble_advertising.h"
#include "ble_bas.h"
#include "ble_conn_params.h"
#include "ble_dfu.h"
#include "ble_dis.h"
#include "ble_hci.h"
#include "ble_srv_common.h"
#include "boards.h"
#include "bsp.h"
#include "bsp_btn_ble.h"
#include "button_status.h"
#include "device_manager.h"
#include "dfu_app_handler.h"
#include "nordic_common.h"
#include "nrf.h"
#include "nrf51_bitfields.h"
#include "nrf_delay.h"
#include "nrf_drv_gpiote.h"
#include "nrf_error.h"
#include "nrf_gpio.h"
#include "pstorage.h"
#include "rtt.h"
#include "softdevice_handler.h"
#include "main.h"


#ifdef DEBUG
#pragma message "---> DEBUG mode turned on!"
#endif

// ===========
// = Buttons =
// ===========

void bsp_evt_handler(bsp_event_t evt) {
    
    if (evt == BSP_EVENT_KEY_0 ||
        evt == BSP_EVENT_KEY_1 ||
        evt == BSP_EVENT_KEY_2 ||
        evt == BSP_EVENT_KEY_3 ||
        evt == BSP_EVENT_KEY_4 ||
        evt == BSP_EVENT_KEY_5 ||
        evt == BSP_EVENT_KEY_6 ||
        evt == BSP_EVENT_KEY_7) {
        uint32_t err_code;
        bool pushed = false;
        uint8_t button_state[BUTTON_STATUS_PACKET_BYTES] = {0xFF, 0x00};
        bool mode_change = false;
        switch (evt)
        {
            case BSP_EVENT_KEY_4:            
            case BSP_EVENT_KEY_5:
            case BSP_EVENT_KEY_6:
            case BSP_EVENT_KEY_7:
                rtt_print(0, "%sMode change #%X%s\n", RTT_CTRL_TEXT_BLUE, evt, RTT_CTRL_RESET);
            
                mode_change = true;
                rtt_print(0, "%sMode Change #%X: %s%X%X(%X)%s\n", RTT_CTRL_TEXT_BRIGHT_BLACK, evt, RTT_CTRL_TEXT_BLUE, button_state[0], button_state[1], mode_change, RTT_CTRL_RESET);
                break;
            default:
                break;
        }
    
        uint32_t num;
        for (num = 0; num < BUTTONS_NUMBER; num++) {
            app_button_is_pushed(num, &pushed);
            if (pushed) {
                button_state[0] ^= (1 << num);
                strncpy(m_last_button_state, button_state, 2);
                m_last_unconnected_button_start = NRF_RTC1->COUNTER;
                rtt_print(0, "%sButton down #%X=%X: %s%X%X(%d)%s\n", RTT_CTRL_TEXT_BRIGHT_BLACK, evt, BSP_EVENT_KEY_0+num, RTT_CTRL_TEXT_BLUE, button_state[0], button_state[1], mode_change, RTT_CTRL_RESET);
                switch (num) {
                    case 0:
                        LEDS_ON(BSP_LED_0_MASK);
                        break;
                    case 1:
                        LEDS_ON(BSP_LED_1_MASK);
                        break;
                    case 2:
                        LEDS_ON(BSP_LED_2_MASK);
                        break;
                    case 3:
                        LEDS_ON(BSP_LED_3_MASK);
                        break;
                    default:
                        break;
                }
            } else {
                rtt_print(0, "%sButton up #%X=%X: %s%X%X(%d)%s\n", RTT_CTRL_TEXT_BRIGHT_BLACK, evt, BSP_EVENT_KEY_0+num, RTT_CTRL_TEXT_BLUE, button_state[0], button_state[1], mode_change, RTT_CTRL_RESET);
                if (evt == BSP_EVENT_KEY_0+num) {
                    if (m_last_press == evt && !mode_change) {
                        button_state[0] ^= (1 << (num+4));
                        rtt_print(0, "%sDouble click! #%X=%X=%X: %s%X%X(%d)%s\n", RTT_CTRL_TEXT_BRIGHT_BLACK, m_last_press, evt, BSP_EVENT_KEY_0+num, RTT_CTRL_TEXT_BLUE, button_state[0], button_state[1], mode_change, RTT_CTRL_RESET);
                    } else if (!mode_change) {
                        rtt_print(0, "%sStoring double click #(%X) %X=%X: %s%X%X(%d)%s\n", RTT_CTRL_TEXT_BRIGHT_BLACK, m_last_press, evt, BSP_EVENT_KEY_0+num, RTT_CTRL_TEXT_BLUE, button_state[0], button_state[1], mode_change, RTT_CTRL_RESET);
                        m_last_press = (bsp_event_t)(BSP_EVENT_KEY_0+num);
                    }
                }
                // button_state[0] |= (1 << 0);
                switch (num) {
                    case 0:
                        LEDS_OFF(BSP_LED_0_MASK);
                        break;
                    case 1:
                        LEDS_OFF(BSP_LED_1_MASK);
                        break;
                    case 2:
                        LEDS_OFF(BSP_LED_2_MASK);
                        break;
                    case 3:
                        LEDS_OFF(BSP_LED_3_MASK);
                        break;
                    default:
                        break;
                }
            }            
        }


        // Mode change
        if (mode_change) {
            m_last_press = BSP_EVENT_NOTHING; // Ignore subsequent double click
            button_state[1] |= 0xFF;
            strncpy(m_last_button_state, button_state, 2);
            LEDS_ON(LEDS_MASK);
        }    
        
        if (!pushed) {
            m_dblclick_timer_start = NRF_RTC1->COUNTER;
            rtt_print(0, "m_doubleclick_timer_id: %X\n", m_doubleclick_timer_id);
            err_code = app_timer_start(m_doubleclick_timer_id, APP_TIMER_TICKS(DOUBLECLICK_DURATION, APP_TIMER_PRESCALER), NULL);
            rtt_print(0, "m_doubleclick app error: %d\n", err_code);
            // APP_ERROR_CHECK(err_code);
        }
        
        if (m_conn_handle != BLE_CONN_HANDLE_INVALID) {
            err_code = ble_buttonstatus_on_button_change(&m_buttonservice, button_state);
            if ((err_code != NRF_SUCCESS) &&
                (err_code != BLE_ERROR_INVALID_CONN_HANDLE) &&
                (err_code != NRF_ERROR_INVALID_STATE) &&
                (err_code != BLE_ERROR_NO_TX_BUFFERS) &&
                (err_code != NRF_ERROR_BUSY) &&
                (err_code != BLE_ERROR_GATTS_SYS_ATTR_MISSING))
            {
                // Can ignore this error, just means that bluetooth is connected but nobody's listening yet
                rtt_print(0, "BLE_ERROR_GATTS_SYS_ATTR_MISSING (or similar)\n");
                // Can ignore this error, just means buffer capacity exceeded (too many button pushes)
                // rtt_print(0, "BLE_ERROR_NO_TX_BUFFERS\n");
                APP_ERROR_HANDLER(err_code);
            }
        } else {
            rtt_print(0, "%sIgnoring button, not connected: %s%X:%X\n", RTT_CTRL_TEXT_BRIGHT_BLACK, RTT_CTRL_TEXT_BLUE, button_state[0], button_state[1]);
            
            LEDS_ON(LEDS_MASK);
            // err_code = ble_advertising_start(BLE_ADV_MODE_FAST);
            // rtt_print(0, "%sStarted BLE advertising fast%s\n", RTT_CTRL_TEXT_BRIGHT_BLUE, RTT_CTRL_RESET);
            // APP_ERROR_CHECK(err_code);
        }
    } else {
        rtt_print(0, "%sUnhandled bsp_evt: %s%X%s\n", RTT_CTRL_TEXT_RED, RTT_CTRL_TEXT_BRIGHT_RED, evt, RTT_CTRL_RESET);
    }
}

// ================
// = Initializers =
// ================

/**@brief Function for initializing low frequency clock.
 */
void clock_initialization()
{
    // https://devzone.nordicsemi.com/question/953/what-low-frequency-clock-sources-can-i-use/
    NRF_CLOCK->LFCLKSRC            = (CLOCK_LFCLKSRC_SRC_Xtal << CLOCK_LFCLKSRC_SRC_Pos);
    NRF_CLOCK->EVENTS_LFCLKSTARTED = 0;
    NRF_CLOCK->TASKS_LFCLKSTART    = 1;

    // Wait for the low frequency clock to start
    while (NRF_CLOCK->EVENTS_LFCLKSTARTED == 0)
    {
        // Do nothing.
    }
    NRF_CLOCK->EVENTS_LFCLKSTARTED = 0;
}


void storage_init() {
    uint32_t err_code;
    
    err_code = pstorage_init();
    
    APP_ERROR_CHECK(err_code);
}

/**@brief Function for initializing bsp module.
 */
void bsp_configuration()
{
    // bsp_event_t startup_event;
    uint32_t err_code;

    err_code = bsp_init(BSP_INIT_LED | BSP_INIT_BUTTONS,
                        APP_TIMER_TICKS(100, APP_TIMER_PRESCALER),
                        bsp_evt_handler);
    APP_ERROR_CHECK(err_code);
    
    // err_code = bsp_btn_ble_init(NULL, &startup_event);
    // APP_ERROR_CHECK(err_code);
}

/**@brief Function for the Event Scheduler initialization.
 *
 * The scheduler is used for transferring execution from the interrupt context to the main context.
 */
static void scheduler_init(void)
{
    APP_SCHED_INIT(SCHED_MAX_EVENT_DATA_SIZE, SCHED_QUEUE_SIZE);
}

// void in_pin_handler(nrf_drv_gpiote_pin_t pin, nrf_gpiote_polarity_t action)
// {
//     nrf_drv_gpiote_out_toggle(PIN_OUT);
//     rtt_print(0, "%sPin toggle: %s%d%s\n", RTT_CTRL_TEXT_YELLOW, RTT_CTRL_TEXT_BRIGHT_YELLOW, pin, RTT_CTRL_RESET);
// }

/**
 * @brief Function for configuring: PIN_IN pin for input, PIN_OUT pin for output, 
 * and configures GPIOTE to give an interrupt on pin change.
 */
// static void gpio_init(void)
// {
//     ret_code_t err_code;
//
//     err_code = nrf_drv_gpiote_init();
//     APP_ERROR_CHECK(err_code);
//
//     nrf_drv_gpiote_out_config_t out_config = GPIOTE_CONFIG_OUT_SIMPLE(false);
//
//     err_code = nrf_drv_gpiote_out_init(PIN_OUT, &out_config);
//     APP_ERROR_CHECK(err_code);
//
//     nrf_drv_gpiote_in_config_t in_config = GPIOTE_CONFIG_IN_SENSE_TOGGLE(true);
//     in_config.pull = NRF_GPIO_PIN_PULLUP;
//
//     err_code = nrf_drv_gpiote_in_init(PIN_IN, &in_config, in_pin_handler);
//     APP_ERROR_CHECK(err_code);
//
//     nrf_drv_gpiote_in_event_enable(PIN_IN, true);
// }

// =================
// = Battery Level =
// =================

/**@brief ADC interrupt handler.
 * @details  This function will fetch the conversion result from the ADC, convert the value into
 *           percentage and send it to peer.
 */
void ADC_IRQHandler(void)
{
    if (NRF_ADC->EVENTS_END != 0)
    {
        uint8_t     adc_result;
        uint16_t    batt_lvl_in_milli_volts;
        uint8_t     percentage_batt_lvl;
        uint32_t    err_code;

        NRF_ADC->EVENTS_END     = 0;
        adc_result              = NRF_ADC->RESULT;
        NRF_ADC->TASKS_STOP     = 1;

        batt_lvl_in_milli_volts = ADC_RESULT_IN_MILLI_VOLTS(adc_result) ;//+ DIODE_FWD_VOLT_DROP_MILLIVOLTS;
        percentage_batt_lvl     = battery_level_in_percent(batt_lvl_in_milli_volts);

        err_code = ble_bas_battery_level_update(&m_bas, percentage_batt_lvl);
        if ((err_code != NRF_SUCCESS)
            &&
            (err_code != NRF_ERROR_INVALID_STATE)
            &&
            (err_code != BLE_ERROR_NO_TX_BUFFERS)
            &&
            (err_code != BLE_ERROR_GATTS_SYS_ATTR_MISSING)) {
            APP_ERROR_HANDLER(err_code);
        }
    }
}

void battery_level_update(void)
{
    uint32_t err_code;

    // Configure ADC
    NRF_ADC->INTENSET   = ADC_INTENSET_END_Msk;
    NRF_ADC->CONFIG     = (ADC_CONFIG_RES_8bit                        << ADC_CONFIG_RES_Pos)     |
                          (ADC_CONFIG_INPSEL_SupplyOneThirdPrescaling << ADC_CONFIG_INPSEL_Pos)  |
                          (ADC_CONFIG_REFSEL_VBG                      << ADC_CONFIG_REFSEL_Pos)  |
                          (ADC_CONFIG_PSEL_Disabled                   << ADC_CONFIG_PSEL_Pos)    |
                          (ADC_CONFIG_EXTREFSEL_None                  << ADC_CONFIG_EXTREFSEL_Pos);
    NRF_ADC->EVENTS_END = 0;
    NRF_ADC->ENABLE     = ADC_ENABLE_ENABLE_Enabled;

    // Enable ADC interrupt
    err_code = sd_nvic_ClearPendingIRQ(ADC_IRQn);
    APP_ERROR_CHECK(err_code);

    err_code = sd_nvic_SetPriority(ADC_IRQn, NRF_APP_PRIORITY_LOW);
    APP_ERROR_CHECK(err_code);

    err_code = sd_nvic_EnableIRQ(ADC_IRQn);
    APP_ERROR_CHECK(err_code);

    NRF_ADC->EVENTS_END  = 0;    // Stop any running conversions.
    NRF_ADC->TASKS_START = 1;
}

uint32_t temperature_data_get(void)
{
    int32_t temp;
    uint32_t err_code;
    
    err_code = sd_temp_get(&temp);
    APP_ERROR_CHECK(err_code);
    
    temp = (temp / 4) * 100;
    
    int8_t exponent = -2;
    return ((exponent & 0xFF) << 24) | (temp & 0x00FFFFFF);
}

/**@brief Function for handling the Battery measurement timer timeout.
 *
 * @details This function will be called each time the battery level measurement timer expires.
 *
 * @param[in] p_context  Pointer used for passing some arbitrary information (context) from the
 *                       app_start_timer() call to the timeout handler.
 */
static void battery_level_meas_timeout_handler(void * p_context)
{
    UNUSED_PARAMETER(p_context);
    battery_level_update();
}

static void doubleclick_timeout_handler(void * p_context) {
    UNUSED_PARAMETER(p_context);
    uint32_t err_code;
    
    if ((NRF_RTC1->COUNTER - m_dblclick_timer_start) < APP_TIMER_TICKS(DOUBLECLICK_DURATION, APP_TIMER_PRESCALER)) {
        rtt_print(0, "%sDouble-click expiring... %s%X: %d < %d%s\n", RTT_CTRL_TEXT_GREEN, RTT_CTRL_TEXT_BRIGHT_GREEN, m_last_press, (NRF_RTC1->COUNTER - m_dblclick_timer_start), APP_TIMER_TICKS(DOUBLECLICK_DURATION, APP_TIMER_PRESCALER), RTT_CTRL_RESET);
        
        err_code = app_timer_stop(m_doubleclick_timer_id);
        APP_ERROR_CHECK(err_code);
        err_code = app_timer_start(m_doubleclick_timer_id, APP_TIMER_TICKS(DOUBLECLICK_DURATION, APP_TIMER_PRESCALER), NULL);
        APP_ERROR_CHECK(err_code);
    } else {
        rtt_print(0, "%sDouble-click expired: %s%X%s\n", RTT_CTRL_TEXT_GREEN, RTT_CTRL_TEXT_BRIGHT_GREEN, m_last_press, RTT_CTRL_RESET);
        m_last_press = BSP_EVENT_NOTHING;
    
        err_code = app_timer_stop(m_doubleclick_timer_id);
        APP_ERROR_CHECK(err_code);
    }
}

// =============
// = Bluetooth =
// =============

/**@brief Function for dispatching a system event to interested modules.
 *
 * @details This function is called from the System event interrupt handler after a system
 *          event has been received.
 *
 * @param[in] sys_evt  System stack event.
 */
static void sys_evt_dispatch(uint32_t sys_evt)
{
    pstorage_sys_event_handler(sys_evt);
    ble_advertising_on_sys_evt(sys_evt);
}

/**@brief Function for handling the Connection Parameters Module.
 *
 * @details This function will be called for all events in the Connection Parameters Module which
 *          are passed to the application.
 *          @note All this function does is to disconnect. This could have been done by simply
 *                setting the disconnect_on_fail config parameter, but instead we use the event
 *                handler mechanism to demonstrate its use.
 *
 * @param[in] p_evt  Event received from the Connection Parameters Module.
 */
static void on_conn_params_evt(ble_conn_params_evt_t * p_evt)
{
    uint32_t err_code;

    if(p_evt->evt_type == BLE_CONN_PARAMS_EVT_FAILED)
    {
        err_code = sd_ble_gap_disconnect(m_conn_handle, BLE_HCI_CONN_INTERVAL_UNACCEPTABLE);
        APP_ERROR_CHECK(err_code);

        rtt_print(0, "%s%sConnection params failed: %s%X%s\n", RTT_CTRL_BG_BRIGHT_RED, RTT_CTRL_TEXT_BRIGHT_WHITE, RTT_CTRL_TEXT_BRIGHT_RED, p_evt, RTT_CTRL_RESET);
    }
}

/**@brief Function for handling a Connection Parameters error.
 *
 * @param[in] nrf_error  Error code containing information about what went wrong.
 */
static void conn_params_error_handler(uint32_t nrf_error)
{
    APP_ERROR_HANDLER(nrf_error);
    rtt_print(0, "%s%sConnection params error: %s%X%s\n", RTT_CTRL_BG_BRIGHT_RED, RTT_CTRL_TEXT_BRIGHT_WHITE, RTT_CTRL_TEXT_BRIGHT_RED, nrf_error, RTT_CTRL_RESET);
}

/**@brief Function for initializing the BLE stack.
 *
 * @details Initializes the SoftDevice and the BLE event interrupt.
 */
static void ble_stack_init(void)
{
    uint32_t err_code;

    // Initialize the SoftDevice handler module.
    SOFTDEVICE_HANDLER_INIT(NRF_CLOCK_LFCLKSRC_XTAL_20_PPM, NULL);
    // SOFTDEVICE_HANDLER_INIT(NRF_CLOCK_LFCLKSRC_RC_250_PPM_4000MS_CALIBRATION, NULL);

    // Enable BLE stack 
    ble_enable_params_t ble_enable_params;
    memset(&ble_enable_params, 0, sizeof(ble_enable_params));
    ble_enable_params.gatts_enable_params.service_changed = IS_SRVC_CHANGED_CHARACT_PRESENT;
    err_code = sd_ble_enable(&ble_enable_params);
    APP_ERROR_CHECK(err_code);

    ble_gap_addr_t addr;

    err_code = sd_ble_gap_address_get(&addr);
    APP_ERROR_CHECK(err_code);
    sd_ble_gap_address_set(BLE_GAP_ADDR_CYCLE_MODE_NONE, &addr);
    APP_ERROR_CHECK(err_code);

    // Register with the SoftDevice handler module for BLE events.
    err_code = softdevice_ble_evt_handler_set(ble_evt_dispatch);
    APP_ERROR_CHECK(err_code);
    
    // Register with the SoftDevice handler module for BLE events.
    err_code = softdevice_sys_evt_handler_set(sys_evt_dispatch);
    APP_ERROR_CHECK(err_code);
    
    // rtt_print(0, "%sStarted bluetooth stack.%s\n", RTT_CTRL_TEXT_MAGENTA, RTT_CTRL_RESET);
}

/**@brief Function for the GAP initialization.
 *
 * @details This function sets up all the necessary GAP (Generic Access Profile) parameters of the
 *          device including the device name, appearance, and the preferred connection parameters.
 */
static void gap_params_init(void)
{
    uint32_t                err_code;
    ble_gap_conn_params_t   gap_conn_params;
    ble_gap_conn_sec_mode_t sec_mode;

    BLE_GAP_CONN_SEC_MODE_SET_OPEN(&sec_mode);

    err_code = sd_ble_gap_device_name_set(&sec_mode,
                                          (const uint8_t *)DEVICE_NAME,
                                          strlen(DEVICE_NAME));
    APP_ERROR_CHECK(err_code);

    // /* YOUR_JOB: Use an appearance value matching the application's use case. 
    err_code = sd_ble_gap_appearance_set(BLE_APPEARANCE_GENERIC_REMOTE_CONTROL);
    APP_ERROR_CHECK(err_code);

    memset(&gap_conn_params, 0, sizeof(gap_conn_params));

    gap_conn_params.min_conn_interval = MIN_CONN_INTERVAL;
    gap_conn_params.max_conn_interval = MAX_CONN_INTERVAL;
    gap_conn_params.slave_latency     = SLAVE_LATENCY;
    gap_conn_params.conn_sup_timeout  = CONN_SUP_TIMEOUT;

    err_code = sd_ble_gap_ppcp_set(&gap_conn_params);
    APP_ERROR_CHECK(err_code);
    
    // rtt_print(0, "%sBluetooth GAP connection params init.%s\n", RTT_CTRL_TEXT_MAGENTA, RTT_CTRL_RESET);
}
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
int main(void)
{
    uint32_t err_code;
    SEGGER_RTT_Init();
    
    rtt_print(0, "%s%sStarting up Turn Touch Remote...%s\n", RTT_CTRL_TEXT_BRIGHT_YELLOW,
                                                          RTT_CTRL_BG_BRIGHT_MAGENTA, 
                                                          RTT_CTRL_RESET);
    
    // Initialize buttons
    clock_initialization();
    // rtt_print(0, "%sInitialized clock%s\n", RTT_CTRL_TEXT_BRIGHT_BLUE, RTT_CTRL_RESET);
    timers_init();
    // rtt_print(0, "%sInitialized timers%s\n", RTT_CTRL_TEXT_BRIGHT_BLUE, RTT_CTRL_RESET);
    bsp_configuration();
    // rtt_print(0, "%sInitialized BSP%s\n", RTT_CTRL_TEXT_BRIGHT_BLUE, RTT_CTRL_RESET);

    // Initialize
    ble_stack_init();
    // rtt_print(0, "%sInitialized BLE stack%s\n", RTT_CTRL_TEXT_BRIGHT_BLUE, RTT_CTRL_RESET);
    scheduler_init();
    // rtt_print(0, "%sInitialized scheduler%s\n", RTT_CTRL_TEXT_BRIGHT_BLUE, RTT_CTRL_RESET);
    device_manager_init();
    // rtt_print(0, "%sInitialized device manager%s\n", RTT_CTRL_TEXT_BRIGHT_BLUE, RTT_CTRL_RESET);
    gap_params_init();
    // rtt_print(0, "%sInitialized GAP Params%s\n", RTT_CTRL_TEXT_BRIGHT_BLUE, RTT_CTRL_RESET);
    advertising_init();
    rtt_print(0, "%sInitialized advertising%s\n", RTT_CTRL_TEXT_BRIGHT_BLUE, RTT_CTRL_RESET);
    services_init();
    // rtt_print(0, "%sInitialized services%s\n", RTT_CTRL_TEXT_BRIGHT_BLUE, RTT_CTRL_RESET);
    conn_params_init();
    // rtt_print(0, "%sInitialized connection params%s\n", RTT_CTRL_TEXT_BRIGHT_BLUE, RTT_CTRL_RESET);
    sec_params_init();
    // rtt_print(0, "%sInitialized security params%s\n", RTT_CTRL_TEXT_BRIGHT_BLUE, RTT_CTRL_RESET);
    battery_level_update();
    // rtt_print(0, "%sInitialized battery level updater%s\n", RTT_CTRL_TEXT_BRIGHT_BLUE, RTT_CTRL_RESET);

    // Start execution
    gpio_start();
    // rtt_print(0, "%sStarted GPIO%s\n", RTT_CTRL_TEXT_BRIGHT_BLUE, RTT_CTRL_RESET);
    application_timers_start();
    // rtt_print(0, "%sStarted application timers%s\n", RTT_CTRL_TEXT_BRIGHT_BLUE, RTT_CTRL_RESET);
    err_code = ble_advertising_start(BLE_ADV_MODE_FAST);
    // rtt_print(0, "%sStarted BLE advertising fast%s\n", RTT_CTRL_TEXT_BRIGHT_BLUE, RTT_CTRL_RESET);
    APP_ERROR_CHECK(err_code);
    err_code = bsp_indication_set(BSP_INDICATE_ADVERTISING);
    APP_ERROR_CHECK(err_code);

    while (true)
    {
        app_sched_execute();
        power_manage();
    }
}


/**
 * @}
 */

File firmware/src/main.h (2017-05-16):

/* Copyright 2015 Turn Touch. All rights reserved.
 *
 * Header for Turn Touch Remote
 */

#include "app_timer.h"
#include "ble_advertising.h"
#include "ble_bas.h"
#include "ble_dfu.h"
#include "button_status.h"
#include "device_manager.h"
#include "pstorage.h"

#define APP_TIMER_PRESCALER      0                           /**< Value of the RTC1 PRESCALER register. */
#define APP_TIMER_OP_QUEUE_SIZE  4                           /**< Size of timer operation queues. */
#define APP_FEATURE_NOT_SUPPORTED            BLE_GATT_STATUS_ATTERR_APP_BEGIN + 2                    /**< Reply when unsupported features are requested. */

// #define BUTTON_PREV_ID           0                           /**< Button used to switch the state. */
// #define BUTTON_NEXT_ID           1                           /**< Button used to switch the state. */
// #ifdef BSP_BUTTON_0
//     #define PIN_IN BSP_BUTTON_0
// #endif
// #ifndef PIN_IN
//     #error "Please indicate input pin"
// #endif
//
// #ifdef BSP_LED_0
//     #define PIN_OUT BSP_LED_0
// #endif
// #ifndef PIN_OUT
//     #error "Please indicate output pin"
// #endif

#define IS_SRVC_CHANGED_CHARACT_PRESENT 1                                           /**< Include or not the service_changed characteristic. if not enabled, the server's database cannot be changed for the lifetime of the device*/

#define DEVICE_NAME                     "Turn Touch Remote"                         /**< Name of device. Will be included in the advertising data. */
#define MANUFACTURER_NAME               "Turn Touch"                                /**< Manufacturer. Will be passed to Device Information Service. */

#define APP_ADV_FAST_INTERVAL           40                                          /**< The advertising interval (in units of 0.625 ms). The default value corresponds to 25 ms. */
#define APP_ADV_SLOW_INTERVAL           3200                                        /**< Slow advertising interval (in units of 0.625 ms). The default value corresponds to 2 seconds. */
#define APP_ADV_FAST_TIMEOUT            5                                          /**< The advertising time-out in units of seconds. */
#define APP_ADV_SLOW_TIMEOUT            86400                                       /**< The advertising time-out in units of seconds. */

#define MIN_CONN_INTERVAL               MSEC_TO_UNITS(100, UNIT_1_25_MS)            /**< Minimum acceptable connection interval (0.5 seconds). */
#define MAX_CONN_INTERVAL               MSEC_TO_UNITS(200, UNIT_1_25_MS)            /**< Maximum acceptable connection interval (1 second). */
#define SLAVE_LATENCY                   4                                           /**< Slave latency. */
#define CONN_SUP_TIMEOUT                MSEC_TO_UNITS(4000, UNIT_10_MS)             /**< Connection supervisory timeout (4 seconds). */

#define FIRST_CONN_PARAMS_UPDATE_DELAY  APP_TIMER_TICKS(5000, APP_TIMER_PRESCALER)  /**< Time from initiating event (connect or start of notification) to first time sd_ble_gap_conn_param_update is called (5 seconds). */
#define NEXT_CONN_PARAMS_UPDATE_DELAY   APP_TIMER_TICKS(30000, APP_TIMER_PRESCALER) /**< Time between each call to sd_ble_gap_conn_param_update after the first call (30 seconds). */
#define MAX_CONN_PARAMS_UPDATE_COUNT    3                                           /**< Number of attempts before giving up the connection parameter negotiation. */
#define BATTERY_LEVEL_MEAS_INTERVAL     APP_TIMER_TICKS(60*60*1000, APP_TIMER_PRESCALER) /**< Battery level measurement interval (ticks). */
#define VBAT_MAX_IN_MV                  3300

#define SEC_PARAM_BOND                  1                                           /**< Perform bonding. */
#define SEC_PARAM_MITM                  0                                           /**< Man In The Middle protection not required. */
#define SEC_PARAM_IO_CAPABILITIES       BLE_GAP_IO_CAPS_NONE                        /**< No I/O capabilities. */
#define SEC_PARAM_OOB                   0                                           /**< Out Of Band data not available. */
#define SEC_PARAM_MIN_KEY_SIZE          7                                           /**< Minimum encryption key size. */
#define SEC_PARAM_MAX_KEY_SIZE          16                                          /**< Maximum encryption key size. */
#define DEAD_BEEF                       0xDEADBEEF                                  /**< Value used as error code on stack dump, can be used to identify stack location on stack unwind. */

#define SCHED_MAX_EVENT_DATA_SIZE       sizeof(app_timer_event_t)                   /**< Maximum size of scheduler events. Note that scheduler BLE stack events do not contain any data, as the events are being pulled from the stack in the event handler. */
#define SCHED_QUEUE_SIZE                10                                          /**< Maximum number of events in the scheduler queue. */
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

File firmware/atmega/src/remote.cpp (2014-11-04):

#include <avr/power.h>
#include <avr/sleep.h>
#include <avr/interrupt.h>
#include <SPI.h>
#include <new.h>
#include <pinchange.h>
#include <RH_RF22.h>
#include <RHReliableDatagram.h>

void sleepNow(void);
void wakeup();
bool run_remote();
void blink(int loops, int loop_time, bool half);
bool detectButtonChange(bool *button_on);

// #define BODS 7      // BOD Sleep bit in MCUCR
// #define BODSE 2     // BOD Sleep enable bit in MCUCR
uint8_t mcucr1, mcucr2;

#define CLIENT_ADDRESS 1
#define SERVER_ADDRESS 2

#define SERIAL_PRINT  1
#define PRESS_ACTIVE  1
#define PRESS_TOGGLE  2
#define PRESS_MODE    3
#define MODE_CHANGE_DURATION 750 // ms
#define BUTTON_DEBOUNCE_DURATION 30 // ms

#if defined(__AVR_ATtiny84__) || defined(__AVR_ATtiny85__)
const int ce_pin           = 2;
const int csn_pin          = 3;
const int led_pin          = 0;
const uint8_t button_pins[] = { 9,10,7,8 };
#else
const int led_pin          = 4;
const int shutdown_pin     = 3; // PD3
const uint8_t button_pins[] = { 5,6,7,8 };
#endif

const uint8_t num_button_pins = 4;
unsigned long button_debounces[num_button_pins];
uint8_t button_states[num_button_pins];
uint8_t button_presses[num_button_pins];
unsigned long button_timestamps[num_button_pins];
volatile unsigned long awakeTime = 0;
const uint64_t pipe = 1;
RH_RF22 radioDriver;
RHReliableDatagram radio(radioDriver, CLIENT_ADDRESS);

void setup() {
    Serial.begin(115200);
    Serial.print("\n\nTurn Touch Remote\n\n");

    pinMode(led_pin, OUTPUT);
    digitalWrite(led_pin, LOW);
    pinMode(shutdown_pin, OUTPUT);
    digitalWrite(shutdown_pin, LOW);

    blink(2, 100, true);
    
    if (!radio.init())
        Serial.println(" ---> Radio client init failed!\n");
    
    // Serial.print(" ---> Temperature: ");
    // Serial.println(radio.temperatureRead(RH_RF22_TSRANGE_M64_64C, 0) * 0.5 - 64);
    
    radio.setTimeout(80);
    radioDriver.setModemConfig(RH_RF22::FSK_Rb125Fd125);
    
    int i = num_button_pins;
    while (i--) {
        pinMode(button_pins[i], INPUT_PULLUP);
        digitalWrite(button_pins[i], HIGH);
        button_timestamps[i] = 0;
        button_presses[i] = 0;
    }

    blink(3, 200, true);
}

void loop() {
    bool button_on = run_remote();

    if (!button_on) {
        if ((millis() - awakeTime) > 250) {
            awakeTime = millis();
            sleepNow();
        }
    }
}

bool run_remote() {
    bool button_on = false;
    bool different = detectButtonChange(&button_on);

    // Send the state of the buttons to the LED board
    if (different) {
        digitalWrite(led_pin, HIGH);
        
        awakeTime = millis();
#ifdef SERIAL_PRINT
        for (uint8_t i=0; i < sizeof(button_presses); i++) {
            Serial.print(button_presses[i], HEX);
        }
#endif
        uint8_t data = 0;
        for (uint8_t i=0; i < sizeof(button_presses); i++) {
            data |= (button_presses[i] << 2*i);
        }
        uint8_t len = sizeof(data);
        bool sent = radio.sendtoWait(&data, len, SERVER_ADDRESS);
        radio.waitPacketSent();
        uint8_t buf[num_button_pins];
        uint8_t from;
        
        if (!sent) { 
#ifdef SERIAL_PRINT
            Serial.println(" ... send failed!");
#endif
        } else if (radio.recvfromAckTimeout(buf, &len, 100, &from)) {
#ifdef SERIAL_PRINT
            Serial.print("\n --> Received from 0x");
            Serial.print(from, HEX);
            Serial.print(": ");
            for (uint8_t i=0; i < sizeof(buf); i++) {
                Serial.print(buf[i], HEX);
            }
            Serial.println();
#endif
        } else {
#ifdef SERIAL_PRINT
            Serial.print(" ... no reply!");
            Serial.println();
#endif
        }
        different = false;
        digitalWrite(led_pin, LOW);
    }

    return button_on;
}

bool detectButtonChange(bool *button_on) {
    // Read the current state of buttons, and test if the current state
    // is different from the last state we sent
    int i = num_button_pins;
    unsigned long button_offset = 0;
    bool different = false;
    
    while (i--) {
        bool button_different = false;
        uint8_t state = !digitalRead(button_pins[i]);

        if (state) *button_on = true;
        
        if (state && !button_debounces[i]) {
            awakeTime = millis();
            button_debounces[i] = millis();
        }
        if (state != button_states[i]) {
            if ((millis() - button_debounces[i]) > BUTTON_DEBOUNCE_DURATION) {
                different = true;
                button_different = true;
                button_states[i] = state;
                button_debounces[i] = 0;
                if (button_timestamps[i]) {
                    button_offset = millis() - button_timestamps[i];
                }
            }
        }

        if (state && button_different) {
            // Start pressing button
            button_timestamps[i] = millis();
            button_presses[i] = PRESS_ACTIVE;
#ifdef SERIAL_PRINT
            Serial.print(" --> Button #");
            Serial.print((int)i+1);
            Serial.print(" pressed: ");
#endif
        } else if (state && !button_different && button_timestamps[i]) {
            // Check if has hit new mode
            button_offset = millis() - button_timestamps[i];

            if (button_offset >= MODE_CHANGE_DURATION) {
#ifdef SERIAL_PRINT
                Serial.print(" --> Mode #");
                Serial.print((int)i+1);
                Serial.print(" by default in ");
                Serial.print((unsigned long)button_offset);
                Serial.print("ms -- ");
#endif
                button_presses[i] = PRESS_MODE;
                button_timestamps[i] = 0;
                different = true;
            }
        } else if (!state && button_different) {
            // Button was pressed, now released
#ifdef SERIAL_PRINT
            Serial.print(" --> Button #");
            Serial.print((int)i+1);
            Serial.print(" released: ");
            Serial.print((unsigned long)button_offset);
            Serial.print(" -- ");
#endif
            button_presses[i] = PRESS_TOGGLE;
            button_timestamps[i] = 0;
        } else if (button_presses[i]) {
            button_presses[i] = 0;
        }
    }
    
    return different;
}
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

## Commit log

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2013-11-18 remote brd fixes (ISP, pulldowns, GND)
    This mirrors the ISP header so it is accessible in the proper
    configuration under the board. It also fixes the some bridging between
    ground and signal from the buttons
    [remote.brd]
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2013-12-09 Adding pin change interface, but it doesn't work for 1/4 pins. Adding serial debugger back in.
    [remote.ino]
2013-12-10 Hardware mode timing. Re-trying send on error, and sending states (active, toggled, mode) since the remote is the new source of truth.
    [remote.ino]
2013-12-10 Fixing broken interrupt. Turns out the pin change library was artificially limiting the PCINTs to 3.
    [remote.ino]
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2013-12-26 Addinga crystall oscillator to remote to fix lost wireless commands.
    [remote.cpp]
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2014-01-23 Redrawing remote to fit 1.5" layout. Adding library for new tactile switch with SMD.
    [Remote.sch, remote.brd]
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2014-03-12 Fixing remote issues with serial monitor.
    [remote.cpp]
2014-03-12 Fixing pcb issue by realizing mosi/miso are switched on pcb, and no resistors needed.
    [Remote.sch, remote.brd]
2014-03-14 Re-laying out the board for the third revision. This one has correct wiring, less expensive crystal, and components in more logical places. Could use some contact points.
    [Remote.sch, remote.brd]
2014-03-29 Swapping MOSI/MISO on radio, isp, and mcu.
    [Remote.sch, remote.brd]
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2014-04-25 Fixing up board.
    [remote.brd]
2014-04-25 Fixing the dumb multi-sends. Now time to debounce.
    [remote.cpp]
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2014-06-05 Moving from nrf24L01+ module to onboard chip. Moving both MCU and radio IC to QFN package.
    [Remote.sch, remote.brd]
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2014-07-29 Correctly sending and receiving. Time to merge.
    [remote.cpp]
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2014-07-31 Revision 9 of the board. Could perhaps use some tweaking. Now uses atmega328p qfn chip.
    [Remote.sch, remote.brd]
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2014-09-15 Revision 10 of the board. Has fixed battery holder and improved programming header location.
    [Remote.sch, remote.brd]
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2014-09-30 Adding screw holes on remote board. Sketching out bottom of enclosure to match screw holes.
    [Remote Enclosure.skp, Remote Enclosure~.skp, Remote.sch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]
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2014-10-20 Fixing speed issues, turning sleep back on.
    [remote.cpp]
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2014-11-08 Revision 13, with new snaptron dome buttons.
    [Remote.sch, remote.brd]
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2014-11-20 New Rhino-ified remote enclosure has four buttons and a top. Just need bottom, screw holes, and bracketing.
    [Remote Enclosure v2.3dm]
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2014-11-21 Enclosure just needs holes on bottom, cut supports, and a filled in side.
    [Remote Enclosure v2.3dm]
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2014-11-24 Filling in sides of enclosure. Also adding screw holes on bottom. Realigning screw holes.
    [Remote Enclosure v2.3dm]
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2014-12-22 Fixing bug where remote would stop trying to connect if a button was pushed while disconnected.
2014-12-22 Switching to BLE112 and new P-Series dome by Snaptron in schematic and board.
    [Remote.sch, remote.brd]
2014-12-23 New P-Series Dome by Snaptron in the eagle pcb. Layout done for revision 14.
    [Remote Enclosure v2.3dm, Remote.sch, remote.brd]
2014-12-23 Stubbing in rev14 of enclosure. Needs pcb brackets, top push down brackets and latches, and buttons.
    [Remote r14.3dm]
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2014-12-24 4 buttons in a block. Need to bend the junction when the top/sides are built.
    [Remote r14.3dm]
2014-12-24 Pouring in side, bending button junctions to compensate. Just need to split the sides, add alignment teeth, and add clasps.
    [Remote r14.3dm]
2014-12-25 Splitting sides, adding grove to connect them back. Just needs cleanup and its ready to go for printing.
    [Remote r14.3dm]
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2014-12-30 Adding tactile version of rev. 14 of board, for use without enclosure.
    [remote.brd, remote.sch]
2015-01-16 New enclsoure with rev15. Still needs to fix bottom of case supports. Also needs to be split into top and bottom.
    [Remote.sch, remote.brd]
2015-01-16 Updating buttons for new, smaller enclosure. Also adding them to blocks. Just need to split the enclosure and snap it back together.
    [Remote r14.3dm]
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2015-01-22 Adding battery level status characteristic and service. Only updates when battery level goes down (except it's in debug mode right now, so it constantly fires).
    [Remote.sch, remote.brd]
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2015-02-05 Flipping buttons from active HIGH to active LOW. Required a lot of fiddling.
2015-02-05 Revision 15 of the board, with active LOW buttons, moved off P1_0/1.
    [Remote.sch, remote.brd]
2015-02-06 Completed rev 16 of the enclosure. Better latches, fixed PCB brackets.
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2015-02-06 Exporting rev 16 of remote enclosure. Moving from OBJ to STL files.
    [bottom.obj, bottom.stl, button.obj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]
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2015-02-28 Adding 0.1mm height to enclosure. Redrawing latches to be locked in xyz, not just zy. No longer chopping off bottom of remote.
2015-03-02 Next revision of enclosure, has north ridge, improved clasps with xyz locking, smoother interlocking with sloping edges to move clasp into lock.
    [bottom.stl, button.stl, top.stl]
2015-03-02 Adding combined buttons STL, since it's cheaper to just print all four buttons at once instead of 4 x button.
    [buttons.stl]
2015-03-06 Adding wedge to buttons to prevent rocking.
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2015-03-17 Fixing interval and latency to better use battery.
2015-03-18 Adding logo and turn touch emboss to bottom. Adding star to orient inside bottom. Raising north ridge on top.
    [button.stp]
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2015-04-01 Revision 18 of enclosure. Has north button bowl, 5 brackets for pcb, logo on bottom.
    [bottom.stp, buttons.stp, top.stp]
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2015-04-17 Redrawing button faces so they are equal and have 0.008" space between them.
    [buttons.stp]
2015-04-18 Further refining buttons. Need to add a ridge to the north button.
    [buttons.stp]
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2015-05-14 Changing multiple item printing links into tubes instead of stacked pyramids. Still need to deboss turn touch on bottom.
    [bottoms.stp, top.stp, tops.stp]
2015-05-16 Reformed model for smooth edges. This may be the final remote for the first prototype batch.
    [buttons.stl, buttons.stp, tops.stp]
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2015-06-05 Cutting up the PCB to fit into the remodeled enclosure. Needs holding pegs.
    [Default Building Storey.sldasm, Default Building.sldasm, Default Project.sldasm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]
2015-06-06 Revision 19 of the pcb, shaped to fit revision 9 of the enclosure (solidworks).
    [Default Site.sldasm, PCB.SLDPRT, Part0.sldprt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]
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2015-06-18 Adding remote buttons export for exporting just the buttons (and not the derived sketch of the top).
    [Remote Buttons Export.ipt, Remote Buttons.0033.ipt, Remote Buttons.0038.ipt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]
2015-06-19 Buttons now have ridges and metal dome switch bumps. They're all done! Now to just get the PCB in, place mounts, and add a lip and snaps.
    [Remote Assembly.0012.iam, Remote Assembly.0014.iam, Remote Assembly.iam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]
2015-06-19 Adding PCB, adding mounts to bottom for PCB. Also adding lip to top and bottom.
    [Eagle PCB.0004.ipt, Eagle PCB.ipt, PCB.STL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]
2015-06-19 Adding magnet holders on bottom. Just need magnet holders on top to finish up.
    [Remote Assembly.0020.iam, Remote Assembly.0022.iam, Remote Assembly.iam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]
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2015-06-24 Fixing bluetooth (just needed to flash softdevice).
    [main.c]
2015-06-25 Adding button service and button status characteristic and firmware nickname characteristic. Both stubbed in. Getting an error on advertisement init.
    [main.c]
2015-06-25 Fixing crashes by shortening advertisement name (data length error).
    [main.c]
2015-06-26 Fixing rev 19's flaws.
    [Remote Buttons Export.0006.ipt, Remote Buttons Export.ipt, Remote Buttons.0065.ipt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]
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2015-06-27 Revision 20 of the pcb. Includes new 6-pin tag connect and nRF51822 Seeed bluetooth module.
    [Remote.sch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]
2015-06-27 Button states should be working on notification now, but they arent. Seems like a firmware bug.
    [main.c]
2015-06-29 Showing error on notification failure.
    [main.c]
2015-06-30 Revision 20 of the enclosure. North ridge needs love, but otherwise should be good.
    [Remote Assembly.0025.iam, Remote Assembly.iam, Remote Bottom.0029.ipt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]
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2015-07-01 Fixing revision 20 of buttons. Adding print joiner.
    [Buttons Mold.iam, Buttons Mold_Remote Buttons_1_LY.iam, Buttons Mold_Remote Buttons_1_MP.ipt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]
2015-07-01 Fixing error on writing to notification. Turns out it was data size.
    [main.c]
2015-07-01 Correctly sending mode change in notification packet.
    [main.c]
2015-07-01 Fixing button issues on both disconnection and during connection.
    [main.c]
2015-07-02 Adding device manager for handling pstorage. Still not entirely sure how it works, but if bonding info is cleared then it doesn't connect.
    [main.c]
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2015-07-15 Fixing issues on revision 20. Button corner stabilizers, buttons lowered, larger logo and rev text on bottom, less deep logo/text.
    [Bottom Mold.iam, Bottom Mold_RG.ipt, Bottom Mold_Remote Bottom_CR_1.ipt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]
2015-07-15 Adding extra corners for snap fit connectors. Beginning to redraw snap fits to accomodate rectangular shape instead of circular shape.
    [remote.brd]
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2015-07-16 Revision 21 of PCB. Additional snap fit holes, also moved to be symmetric.
    [remote.brd]
2015-07-16 Revision 21 of enclosure. New round snap fit connectors, added 2 for a total of 6 connectors.
    [Eagle PCB rev 21.0009.ipt, Eagle PCB rev 21.ipt, PCB.SLDPRT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]
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2015-07-16 Fixing buttons for export rev 21.
    [Remote Buttons Export.0008.ipt, Remote Buttons Export.0009.ipt, Remote Buttons Export.ipt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]
2015-07-17 Adding Case Top and adding inserts for top case to mate with top remote.
    [Case Top.0001.ipt, Case Top.ipt, Remote Shell.0008.ipt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]
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2015-07-18 CAM for bottom. Needs tabs and a fix for the t-slot milling of the inner tab.
    [Case Bottom.0003.ipt, Case Bottom.0005.ipt, Case Bottom.ipt]
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2015-07-31 Finished CAM for Case Bottom. Now need to replace both tool bits and draw the appropriate trace path for the undercuts.
    [Case Bottom.ipt]
2015-08-04 Adding logo to be engraved. Also finalizing bits. Just need to draw t-slot undercutting traces.
    [Case Bottom.ipt]
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2015-08-06 Fixing Case Bottom's mating tabs to fit below the border. Re-doing CAM for top of bottom case.
    [Case Bottom.ipt, Case Top.ipt, Remote Top.ipt]
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2015-08-06 Updating assembly with fixed bottom.
    [Case Top.ipt, Remote Assembly.iam, Remote Buttons Export.ipt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]
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2015-08-06 Finishing CAM on case bottom. Now need to replace button pegs.
    [Case Bottom.ipt, Remote Assembly.iam, Remote Buttons Export.ipt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]
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2015-08-07 Redrawing north ridge on case buttons and removing broken north ridge from remote buttons.
    [Case Buttons.ipt, Remote Assembly.iam, Remote Buttons.ipt]
2015-08-07 Fixing remote buttons. Cleaning up.
    [Case Buttons.ipt, Remote Assembly.iam, Remote Buttons.ipt]
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2015-08-21 Sticking bootloader on same hex as app. Still doesn't restart into DFU mode properly, though.
    [main.c]
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2015-08-25 Correctly setting button status service's firmware nickname characteristic correctly based on pstorage.
    [main.c, main.h]
2015-08-28 Updating to latest sdk. Bootloader doesn't load app correctly, unfortunately.
    [main.c]
2015-08-28 Finally got the keil debugger worker. Now it looks like the timer is broken.
    [main.h, nrf_drv_config.h]
2015-09-03 Adding a bit of logging. Also trying to fix the Keil version.
    [main.c]
2015-09-03 Fixing longpress and button up on Keil-compiled remote. Looks like its done and now ready to work on DFU.
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2015-09-16 Revision 28 of the board. Fixing VDD/GND mixup.
    [Remote.sch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]
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2015-10-14 Fixing DFU issues by following the trail. Was losing connection handle, now giving dfu events higher priority.
    [main.c, main.h]
2015-10-14 Fixing gcc to auto-load the app when flashing bootloader + sd + app.
    [main.c, main.h]
2015-10-21 Fixing buttons turning off during disconnection.
    [main.c]
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2015-11-18 Disabling broken logs in device manager.
2015-11-20 Fixing BSP in SDK 10.
    [main.h]
2015-12-04 Adding logging and pin reset to firmware.
    [main.c]
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2015-12-09 Adding restrict to snaptron dome layout between contacts. Also widening vent hole.
    [Remote.sch, remote.brd]
2015-12-14 Adding double-click handler (with early expiring app timer bug handled). Firmware v3.
    [main.c, main.h]
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2016-01-26 v4 - fixes device restart when holding down 3 or 4 buttons.
    [main.c, main.h]
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2016-04-20 v5: shorter interval for mode change
    [main.h]
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2017-03-12 Updating BOM to include correct MDBT40-R256V3
    [Remote.sch, Tempo - Turn Touch Remote BOM rev 30.xlsx, Turn Touch Remote BOM rev 30.csv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]
2017-03-14 Rev 35 of remote board. Includes fixes for current consumption, button debouncing, and updated BOM.
    [Remote.brd, Remote.sch, Turn Touch Remote BOM rev 30.csv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]
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2017-03-14 Updating rev 35 to move the peg so as not to interfere with the button arms.
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2017-03-22 Correcting clock trace issue. Rev 37.
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2017-08-15 Updating cream layer on cr2032 to prevent accidental solder paste on battery holder.
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2017-09-11 Fixing copper layer issue where the GND terminal of the battery isnt electrically connected.
    [turntouch-remote-master.brd, turntouch-remote-master.sch]
2017-09-26 Latest gerbers for rev 40 (with fixed ground).
    [turntouch-remote-master.brd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]
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

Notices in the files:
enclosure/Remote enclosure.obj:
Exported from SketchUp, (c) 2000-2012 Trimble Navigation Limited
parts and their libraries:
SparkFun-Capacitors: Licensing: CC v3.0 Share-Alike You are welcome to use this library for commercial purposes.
